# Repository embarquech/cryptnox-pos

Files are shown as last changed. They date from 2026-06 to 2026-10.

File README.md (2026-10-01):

<div align="center">



### cryptnox-pos

Standalone USDC payment terminal powered by a Cryptnox smart card and the Cheap Yellow Display

</div>

<br/>
<br/>






`cryptnox-pos` is a self-contained payment terminal firmware that runs on the
ESP32-2432S028 "Cheap Yellow Display" (CYD). It also serves as a reference
**dev kit** showing how to integrate the [`cryptnox-sdk-esp32`](https://github.com/embarquech/cryptnox-sdk-esp32)
into a real-world end-user product.

The user selects an amount on the touchscreen, taps a **Cryptnox smart card** on
the attached PN532 reader, and the terminal signs and broadcasts an EIP-1559
transfer via a JSON-RPC endpoint (PublicNode by default), then waits for the
on-chain receipt before showing **Approved**. The asset is picked on the device —
ETH, USDC or USDT on Ethereum, POL, USDC or USDT on Polygon, and TRX or USDT on
Tron. Whether those are the production networks or their test deployments
(Sepolia, Amoy, Nile) is a runtime setting on the config page; it defaults to
**production**, and the terminal restarts to apply a change. USDC on Tron is a
testnet-only selection — Circle wound it down in 2024&ndash;25.

> [!NOTE]
> The keypad enters two decimal places of whatever asset is selected, and a
> native-coin amount is signed as a `uint64` of wei — so **ETH and POL sales are
> capped at 18.44**. The keypad stops there rather than letting an operator key a
> figure the transaction cannot carry. The stablecoins are 6-decimal and keep the
> full 99999.99 range.

> [!WARNING]
> **Reference / educational dev kit — not a tamper-resistant terminal.**
> The ESP32 is not a secure microcontroller and has no protected RAM. The
> optional [secure build](#secure-build)
> (Flash Encryption + encrypted NVS + Secure Boot v2) protects secrets at rest
> and locks the boot chain, but at run time the card PIN (entered on-screen, not
> stored in the firmware) and the Wi-Fi password live in plaintext RAM —
> readable by anyone who can reach live memory (JTAG, a run-time exploit).
> **The Cryptnox Hardware Wallet remains the trust anchor** — private keys never
> leave the card, so a compromised ESP32 still cannot sign without it.

### Built on

- **[`cryptnox-sdk-esp32`](https://github.com/embarquech/cryptnox-sdk-esp32)** (git submodule) — secure channel, ECDH/ECDSA, PN532 transport, ESP32 crypto provider
- **[LVGL 8](https://lvgl.io/)** (managed component) — the touchscreen UI
- **[TFT_eSPI](https://github.com/Bodmer/TFT_eSPI)** + **[XPT2046_Touchscreen](https://github.com/PaulStoffregen/XPT2046_Touchscreen)** (git submodules) — CYD panel driver + touch, behind LVGL
- **[arduino-esp32](https://github.com/espressif/arduino-esp32)** as an ESP-IDF managed component (Arduino runtime for the display libraries; the rest stays on native IDF)

---

## Supported hardware

### Cryptnox Hardware Wallet smart cards

Works with Cryptnox Hardware Wallet smart cards running firmware v1.6.0 or later.

| Smart card | Wallet version |
|---|---|
| [Crypto Hardware Wallet – Dual Card Set](https://shop.cryptnox.com/product/hardware-wallet-smartcard-dual/) | v1.6.1 |

### NFC readers

| Reader | Type | Interface |
|---|---|---|
| [PN532 NFC Module](https://www.nxp.com/products/PN532) | Contactless (NFC/ISO 14443) | I²C |

### Host board

| Board | MCU | Display | Touch |
|---|-----|---|---|
| [ESP32-2432S028 "Cheap Yellow Display"](https://github.com/witnessmenow/ESP32-Cheap-Yellow-Display) | ESP32-WROOM-32 | ILI9341 240×320 (portrait) | XPT2046 (resistive) |

---

## Installation

1. Install **[ESP-IDF v5.5](https://docs.espressif.com/projects/esp-idf/en/v5.5/esp32/get-started/index.html)**
   (the project pulls `espressif/arduino-esp32` and `lvgl/lvgl` as IDF managed
   components; TFT_eSPI / XPT2046 are in-tree submodules).
2. Clone this repository **with submodules**:
   ```
   git clone --recursive https://github.com/embarquech/cryptnox-pos.git
   cd cryptnox-pos
   ```
3. Copy the credentials template and fill it in:
   ```
   cp config.template.h main/config.h
   ```
   `main/config.h` is gitignored — see [Configuration](#configuration) below.
4. Set the target, then build and flash from an ESP-IDF environment:
   ```
   idf.py set-target esp32
   idf.py -p PORT build flash monitor
   ```
   The first build also fetches `espressif/arduino-esp32` and `lvgl/lvgl` from
   the IDF component registry, so expect a longer initial compile.

> [!TIP]
> Open the IDF env first: on Windows run the "ESP-IDF PowerShell"/`export.bat`,
> on macOS/Linux `. $IDF_PATH/export.sh`. For the **secure (encrypted/signed)
> build**, see [Secure build](#secure-build)
> below — don't use plain `idf.py flash` on an already-provisioned board.

## Hardware setup

> [!CAUTION]
> Always double-check the wiring before powering the board to prevent damage.

The CYD exposes its free GPIOs on the **CN1** header. The firmware uses
the **I²C** interface to the PN532.

### CYD CN1 ↔ PN532 NFC — I²C interface

| PN532 Pin | CYD Pin / Label  | Wire Color |
|---|---|---|
| GND | GND | Black |
| VCC | 3.3V | Red |
| SDA | GPIO 27 (CN1 SDA)| Yellow |
| SCL | GPIO 22 (CN1 SCL)| Blue |

> [!IMPORTANT]
> Set the PN532 module's mode switches to **I²C = `1 0`**, as printed on the
> board: the switch marked **1** ON (HIGH), the switch marked **2** OFF (LOW).
> `0 1` is SPI.
>
> The PN532 reads the switches only at its own power-up, and its reset pin is not
> wired, so an ESP32 reset does not apply a change — unplug and replug the USB.

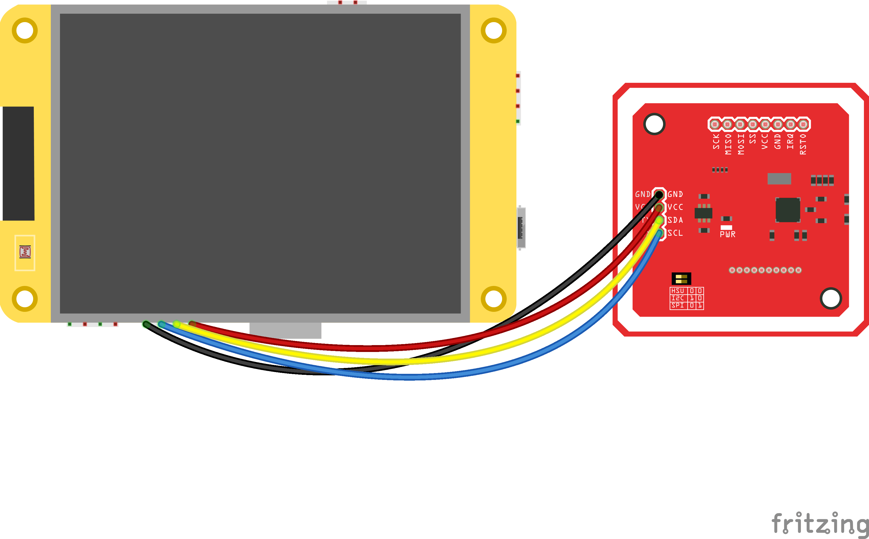
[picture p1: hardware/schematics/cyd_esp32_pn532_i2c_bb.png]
cyd_pn532_i2c


The display, touchscreen and backlight pins are already wired internally on the
CYD; the firmware drives them through TFT_eSPI's `ILI9341_2_DRIVER` in **portrait
rotation (240×320)**, with `invertDisplay(true)` + a GAMMASET fix for the panel
and a calibrated XPT2046 touch mapping. The backlight is PWM-dimmable (LEDC).

---

## Configuration

`main/config.h` is gitignored. Copy `config.template.h` to `main/config.h`
and fill in:

| Field | Description |
|---|---|
| `RPC_URL` | Ethereum JSON-RPC endpoint (PublicNode Sepolia by default; an Infura variant is provided commented-out) |
| `RPC_PROJECT_ID` / `RPC_API_SECRET` | Optional — only when using Infura (HTTP Basic Auth); leave undefined for PublicNode |
| `RPC_CA_CERT_PEM` | Optional — pin the RPC endpoint's TLS certificate; trusts only that cert instead of the full CA bundle. Undefined = Mozilla bundle |
| `ADDR_FROM` | Any valid Ethereum address, used only as the boot-time RPC reachability probe. The paying account is derived from whichever card is tapped (`m/44'/60'/0'/0/0`), not read from here |
| `ADDR_TO` | **Fallback** destination address, used until an operator sets one on the device. **Use the EIP-55 mixed-case checksum form** — the firmware verifies the checksum at boot and refuses to start on a mismatch. All-lowercase is accepted but bypasses that typo protection (and warns at boot) |
| `ADDR_USDC` | **Fallback** USDC ERC-20 contract address on the target chain (Sepolia testnet by default). Same EIP-55 rule as `ADDR_TO` |
| `ADDR_USDT` | USDT ERC-20 contract on Sepolia. Not settable on the device — the one NVS contract slot is USDC's — and not fatal if unset: USDT on Ethereum is then refused at the confirm step. Its `decimals()` **must be 6**. Same EIP-55 rule as `ADDR_TO` |
| `POLY_RPC_URL`, `CHAIN_ID_AMOY`, `POLY_ADDR_USDC`, `POLY_ADDR_USDT` | Polygon Amoy endpoint, chain id and the two token contracts on that network. Polygon reuses the whole Ethereum path — same card key, same payout address — so only these differ. `POLY_CA_CERT_PEM` pins its certificate; `POLY_MIN_PRIORITY_FEE_GWEI` (default 30) is the tip floor, since Amoy drops anything under ~25 Gwei and the fee steppers are shared with Ethereum |
| `TRON_ADDR_USDC` | USDC TRC-20 contract on Nile. Config-only and non-fatal, like `ADDR_USDT`. Testnet only: Circle wound USDC on Tron down in 2024–25, so there is no mainnet asset to graduate to |
| `RPC_URL_MAIN`, `POLY_RPC_URL_MAIN`, `TRON_URL_MAIN`, `CHAIN_ID_MAINNET`, `CHAIN_ID_POLYGON`, `ADDR_USDC_MAIN`, `ADDR_USDT_MAIN`, `POLY_ADDR_USDC_MAIN`, `POLY_ADDR_USDT_MAIN`, `TRON_ADDR_USDT_MAIN`, `TRON_ADDR_USDC_MAIN` | The production half of every pair above, selected at run time from the config page's Network section (default: production). Same rules throughout — EIP-55 form, `decimals()` **must be 6**, unset means that asset is refused rather than the terminal failing to boot. `tests/units/test_networks.cpp` checks each one parses; **verify against a block explorer** that it is the right contract before taking real money. A TLS pin applies to the production endpoint too, so it has to cover whichever network the terminal is switched to |
| `CHAIN_ID_SEPOLIA`, `MAX_PRIORITY_FEE`, `MAX_FEE`, `GAS_LIMIT_ERC20` | Chain ID and EIP-1559 gas parameters (the fees are first-boot defaults, editable at run time in the settings) |
| `GAS_LIMIT_NATIVE` | Gas for a plain ETH/POL transfer — exactly 21000, since no contract runs. Optional; defaults to 21000 |

**Not in `config.h`** — set on the device, never baked into the firmware:
- **Wi-Fi** — chosen during setup from a list the terminal scans, in a browser (stored in NVS).
- **Payout addresses and token contracts** — set during setup, either typed in a
  browser or read off the operator's own Cryptnox card, and accepted on the panel.
  The `config.h` values above are only the fallback; an asset with no address of its
  own is **not offered** on the amount screen.
- **Card PIN** — entered on the touchscreen keypad at sign time, scrubbed from RAM right after.
- **Transfer amount** — chosen on the keypad per transaction.

Setup itself is a browser flow — see [docs/config-portal.md](docs/config-portal.md):

```
 admin code    panel     the one secret that never touches a network
 QR code       panel     camera joins the terminal's AP; the page opens itself
 authorise     both      the browser asks, the panel takes the code
 addresses     browser   typed, or read off a Cryptnox card
 Wi-Fi         browser   picked from the terminal's own scan
 Finish        panel     restarts, which applies everything
```

---

## Secure build

By default the firmware and NVS are **unencrypted and unsigned** — fine for the
dev kit. An optional **secure build** hardens the device on three fronts:

| Feature | Effect |
|---|---|
| Flash Encryption | a flash dump is ciphertext, useless without the key |
| Encrypted NVS (`nvs_keys` partition) | the Wi-Fi password / fees in NVS are encrypted |
| Secure Boot v2 (RSA-3072) | only firmware signed with your key boots |

> [!CAUTION]
> These burn **eFuses — IRREVERSIBLE**. Validate on a **sacrificial board
> first**; a misconfigured burn bricks the unit. On the classic **ESP32**
> Secure Boot v2 supports **a single key with no revocation/rotation** (that
> is an S2/S3/C-series feature): if your signing key leaks you cannot revoke
> it, and if you lose it the board can never be updated again. Keep both keys
> **offline, in multiple copies**.

In the repo:
- `sdkconfig.defaults.flash_encryption` — **DEVELOPMENT** secure overlay: Flash
  Encryption (Development mode), `CONFIG_NVS_ENCRYPTION`, Secure Boot v2 +
  signing key, `ESP32_REV_MIN_3` (required for SBv2) and
  `PARTITION_TABLE_OFFSET=0x10000`. Stays reflashable, keeps verbose logs.
- `sdkconfig.defaults.release` — **RELEASE** overlay (layer on top): Flash
  Encryption *Release* mode + boot log off. Locks the board — no plaintext
  flash, no flash dump. Production only, irreversible.
- `partitions.csv` — the `nvs_keys` partition (inert in a normal build).
- `tools/secure_provision.py` — one-shot factory provisioning of a fresh board.
- `tools/secure_flash.py` — pre-encrypt + flash for routine reflashing.

**Step 1 — generate both keys, ONCE per product (store OFFLINE, gitignored):**
```
espsecure.py generate_flash_encryption_key --keylen 256 secure_keys/flash_encryption_key.bin
espsecure.py generate_signing_key --version 2 secure_keys/secure_boot_signing_key.pem
```

**Step 2 — build with the secure overlay** (the bootloader + app are signed
automatically at build time):
```
idf.py -D "SDKCONFIG_DEFAULTS=sdkconfig.defaults;sdkconfig.defaults.flash_encryption" build
```
(PowerShell: quote the whole `-D` argument as shown, because of the `;`.)

**Step 3 — provision a fresh board (one command, IRREVERSIBLE):**
```
python tools/secure_provision.py --port COMx --baud 921600 --yes
```
It checks the board is fresh, burns the flash-encryption key, enables Flash
Encryption, then flashes the signed + pre-encrypted bootloader/table/app. After
it finishes, **reset the board**: the bootloader finalizes Secure Boot on first
boot (burns the public-key digest + `ABS_DONE_1`). Verify:
```
espefuse.py --port COMx summary | findstr "FLASH_CRYPT_CNT ABS_DONE_1"
```
→ `FLASH_CRYPT_CNT` odd and `ABS_DONE_1 = True` = fully hardened.

**Routine reflash afterwards** (board already provisioned, Flash Encryption
active — never use plain `idf.py flash`, it would write plaintext the chip
mis-decrypts):
```
python tools/secure_flash.py --port COMx --baud 921600              # full
python tools/secure_flash.py --port COMx --baud 921600 --app-only   # app only
```
Because images are pre-encrypted on the host, `FLASH_CRYPT_CNT` is never
consumed. To **distribute** an encrypted image instead of flashing locally:
```
python tools/secure_flash.py --package    # -> dist/cryptnox_pos-encrypted-full.bin
```

> [!WARNING]
> Steps 2–3 use the `flash_encryption` overlay = **Development** mode: the board
> stays reflashable with verbose logs while you validate. For the locked
> **production** image, layer the release overlay on top and reflash:
> ```
> idf.py -D "SDKCONFIG_DEFAULTS=sdkconfig.defaults;sdkconfig.defaults.flash_encryption;sdkconfig.defaults.release" build
> ```
> Release mode permanently disables plaintext UART flashing + flash dumps and
> silences the boot log — IRREVERSIBLE, manufacturing only. Note: on the classic
> ESP32 encrypted NVS **requires** Flash Encryption (no HMAC eFuse scheme), so
> the two cannot be separated.

---

## Payment flow

1. **Splash** — Cryptnox logo + spinner while Wi-Fi / SNTP / RPC / wallet come
   up (version shown at the bottom).
2. **Amount** — numeric keypad (cents entry); tap **Charge**.
3. **Send** — Ledger-style review showing the amount, the destination address
   and the USDC contract **in full**; tap **Confirm** or **Cancel**.
4. **PIN** — enter the card PIN on the on-screen keypad (validated, then wiped
   from RAM after signing — never stored).
5. **Transaction** — tap the Cryptnox card on the PN532:
   **Processing** (opening the secure channel) → **Signing** (the card signs
   `keccak256(unsigned_tx)`) → **Authorizing** (work out the `v` parity locally
   against the card's own public key, RLP-encode the EIP-1559 tx, broadcast via
   `eth_sendRawTransaction`) → **Confirming** (poll `eth_getTransactionReceipt`
   until the tx is mined).
6. **Approved / Declined** — Approved **only** on a mined receipt with
   `status 0x1`; tap **New sale** to start the next transfer.

> [!NOTE]
> The card must have a seed loaded and the BIP-32 derivation path
> `m/44'/60'/0'/0/0` available. Provision it once with the
> [Cryptnox CLI](https://github.com/cryptnox/cryptnox-cli):
> ```
> cryptnox initialize
> cryptnox seed generate
> ```

---

## Troubleshooting

- **Inverted colours / banding on gradients** → the CYD panel needs `invertDisplay(true)` (inverted colours) and a GAMMASET tweak (banding/"milky gamma"); both are already applied in `ui_task`. If the screen is blank/scrambled your board may use the other ILI9341 variant — set `CONFIG_TFT_ILI9341_DRIVER=y` (instead of `_2`) in `sdkconfig.defaults` and rebuild.
- **Touch hitboxes are offset** → calibrate the panel: burger menu → admin code → **Screen** → **Touch**. Two crosses to tap, then Keep or Discard the result, and an un-confirmed calibration puts the old one back after 20 s — so a bad one cannot lock you out of the screen that fixes it. The defaults (raw 200..3800) match the panel shipped with the 2432S028. The stored range lives in NVS, so it goes the way every other setting does: a factory reset or a firmware update with a new `BUILD_ID` clears it and the panel is back on the defaults.
- **`Card not found`** → confirm the PN532 switches are set for I²C (`1 0`, then power-cycle), the SDA/SCL wires match GPIO 27/22, and the card is well centred on the antenna. `pn532: No ACK from PN532` at boot means the reader is not answering at all — almost always the switches. A reader that stops answering later is re-initialised by the driver on its own (`re-initialising the reader` in the log).
- **`Signature check failed`** → the card's signature did not verify under the public key it exported for the same path. That is an internal inconsistency (card or derivation), not a setup error — retry with the card held still; if it repeats, the card needs looking at.
- **WiFi connect fails** → only WPA2 is supported; check SSID/password.
- **App partition full** → the project uses two 1.94 MB OTA app slots (`partitions.csv`) on a 4 MB flash, so the budget is half what a single-slot table would give — a "% free" that halved between two builds is almost always that table, not growth. Where the space actually goes, biggest first: the image assets in `.rodata` (`chain_icons.c`, `logo_img.c` — ~40 KB between them), then LVGL and the fonts it pulls in. Regenerate an asset smaller (`tools/gen_*.py`), or trim the panel fonts: they are generated by `tools/gen_fonts.py` into `main/fonts/*.c` (Plus Jakarta Sans + Inter, 4 bpp — the LVGL built-in Montserrat fonts are already off), so fewer sizes or a narrower glyph range there is where font space comes back; check with `idf.py size-components` before assuming a subsystem is to blame.
- **`Update` says the terminal has no second firmware slot** → that unit was flashed with the old single-app partition table. The table itself is never rewritten by an update, so it needs one reflash over USB first. See [docs/ota.md](docs/ota.md).

---

## Documentation

The generated documentation for this project is available [here](https://embarquech.github.io/cryptnox-pos/).

- [The config portal](docs/config-portal.md) — setup and administration on the terminal's own SoftAP: why that AP is the radio's only interface while the page is up, why the admin code is only ever typed on the panel, and the endpoint list. Test plan: [docs/testing-provisioning.md](docs/testing-provisioning.md).
- [Firmware updates over Wi-Fi](docs/ota.md) — the browser-mediated OTA path, publishing a release, and the signing key you must not ship without. Test plan: [docs/ota-testing.md](docs/ota-testing.md).

---

## License

`cryptnox-pos` is dual-licensed:

- **LGPL-3.0** for open-source projects and proprietary projects that comply with LGPL requirements
- **Commercial license** for projects that require a proprietary license without LGPL obligations

For commercial inquiries, contact: contact@cryptnox.com

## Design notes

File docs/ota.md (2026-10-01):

# Firmware updates over Wi-Fi

The terminal never connects to GitHub. A browser does, and carries the bytes:

```
 you:     download cryptnox_pos.bin anywhere with internet
 browser ──HTTP──>  http://192.168.4.1/api/ota                  streamed to flash
 panel:   operator accepts the version → reboot into the other slot
```

Why the browser and not `esp_https_ota`, which would be a tenth of the code: a
terminal that phones a third party for updates tells that third party how many
units exist, roughly where they are and what each one runs. Nobody needs a
register of deployed payment terminals, least of all one kept by somebody else.

Firmware slots and image verification are `main/ota.cpp`, and the reasoning lives
in `main/ota.h`. The page, the endpoint and the authorisation belong to the config
portal — see **[config-portal.md](config-portal.md)**, which is also where the
addresses and contracts are set. Firmware is one section of one page.

## Why the flow has this shape

The page is on the terminal's own SoftAP and nowhere else — that AP is the
radio's only interface while the config portal is up, which is what keeps the
payout forms off the venue LAN (see
[config-portal.md](config-portal.md)). So the browser reading the page is on a
network with no route to the internet, and there is exactly one way to feed it an
image: **Browse**, and pick a `.bin` that is already on the phone or laptop.
Download it — desk, phone, USB stick — *before* joining the terminal's AP.

There used to be a "Check for updates" button that fetched a `firmware.json`
release list from the browser. It is gone. It only ever worked when a phone
happened to keep cellular data alive alongside a Wi-Fi network with no route,
which is not something to build on, and the other 90% of the time it was a
button whose only output was a network error. Publishing a release is now
publishing a signed `.bin` somewhere people can download it.

### What the transport is worth, and what it is not

The **firmware** does not need the transport to be trustworthy — it is verified
against a signing key compiled into the running image (see below), so a modified
upload is rejected whatever the network did to it.

The **admin code** is not on the network at all. It is typed on the terminal's own
screen to authorise the browser, and the browser then carries a random session
token; there is no code field in the page and no `X-Admin-Code` header any more.
See the authorisation section of [config-portal.md](config-portal.md).

The page is served over plain HTTP on the terminal's own WPA2 SoftAP, which
admits one station at a time and is the radio's only interface while the portal is
up. That link, not a certificate, is what protects the session token and the
addresses on the page — and neither is what keeps a stranger's firmware off the
device. The signature is.

## Operating it

1. Settings → About → **Update** (or Wi-Fi → **Configure**; same page). The panel
   shows a QR code for the terminal's own Wi-Fi, the SSID and passphrase in text,
   and starts a **15-minute** window (`PROV_WINDOW_MIN`). Tapping **Done** closes
   it immediately — and puts the terminal back on its network, which it leaves for
   the duration.
2. Scan the code with a phone camera to join, and the page opens itself. The panel
   asks for the admin code; enter it there. Then **Browse** and pick the `.bin`
   (see above — download it *before* joining). Picking it starts the transfer;
   there is no second confirm button, because nothing the page does installs
   anything.
3. The terminal verifies the image and asks on its own screen. Nothing reboots
   until somebody accepts it there — the same rule payout addresses follow: a
   browser may propose, only the panel may accept. A version that goes
   *backwards* is called out in red.
4. First boot after an update is on probation. `ota_mark_valid()` runs only once
   the panel, the card reader and the wallet layer have all come up; a reset
   before that point returns the bootloader to the previous slot. The network is
   deliberately not part of it: the first boot after an update runs setup (the
   update wipes the settings), and a power cut or an RPC outage during setup must
   not roll back an image that works.

## Publishing a release

There is no manifest and no URL compiled into the firmware: a release is a
signed `cryptnox_pos.bin` put somewhere operators can download it (a GitHub
release asset is fine), fetched *before* joining the terminal's AP and then
picked with **Browse**.

The version is built from git, never from a file: `<latest tag>-<first-parent
commit count>-g<short hash>`, e.g. `v1.0.0-91-gc10d526` (project
`CMakeLists.txt`). A release is a tag — `git tag v1.1.0` on the release commit,
then push the tag. The commit count doubles as `BUILD_ID`, which decides whether
the terminal wipes its settings on first boot. The panel
compares the uploaded image's version with the running one and calls out a
*downgrade* in red before anything is installed. Ordering is dotted-numeric with
an optional leading `v`; anything after the numbers (`-rc1`, `+sha`) is ignored
rather than ordered (`main/ota_version.h`, `tests/units/test_ota_version.cpp`).

## Signing — do not ship without this

The terminal cannot validate a TLS certificate chain to GitHub, because it never
talks to GitHub. Its only way to know an image is genuine is a signature over
that image, checked against a public key compiled into the firmware already
running. The secure build turns that on — `sdkconfig.defaults.flash_encryption`
enables hardware Secure Boot v2, and `sdkconfig.defaults.release` stacks on top
of it — and `esp_ota_end()` refuses anything that fails it, before the staged
slot can ever become bootable.

Without it, `POST /api/ota` is one authorised browser session away from replacing
the firmware on a device that signs cryptocurrency transactions. The session token,
the 15-minute window and the on-screen accept are not a substitute — they make it
harder to reach, not impossible, and none of them can tell a genuine image from a
convincing one.

This is **hardware** Secure Boot v2: the first boot of a secure build burns the
signing key's digest into eFuse, and that is one-way — from then on the unit only
boots, and only installs, images signed with the same key. (An earlier version of
the release overlay tried to add the software-only variant on top; Kconfig drops
it whenever `CONFIG_SECURE_BOOT` is set, so both overlays now name the one model
and the one key.)

Generate the key once:

```sh
idf.py secure-generate-signing-key --version 2 secure_keys/secure_boot_signing_key.pem
```

Keep it out of this repository and off any build machine you do not control; it
is the whole of the trust anchor. Losing it means no unit already in the field
can ever be updated again. The RSA scheme needs ESP32 revision v3.0 (ECO3) —
if `esptool.py chip_id` reports less, switch to
`CONFIG_SECURE_SIGNED_APPS_ECDSA_SCHEME` and drop `CONFIG_ESP32_REV_MIN_3`.

## Flash budget

`partitions.csv` carries two 1.94 MB app slots (`ota_0`, `ota_1`) — the largest
64 KB-aligned pair that fits in 4 MB alongside the data partitions. The image is
~1.6 MB, so there is roughly 390 KB of headroom; check `idf.py size` before
adding fonts or images.

**A unit flashed with the old single-slot table cannot be updated over the air.**
The partition table is never rewritten by an update, so those units need one
serial reflash before any of this applies to them.

## Endpoints

Firmware uses two of the portal's; the full list is in
[config-portal.md](config-portal.md).

| | |
|---|---|
| `GET /api/state` | includes `version`, the running firmware's, for the page's header |
| `POST /api/ota` | image body, `X-Prov-Token` header, streamed to the idle slot |

Same-origin, so no CORS headers are needed on the device side and no preflight
happens. The page does not hash the file itself — `crypto.subtle` is not even
available to it, since `http://192.168.4.1/` is not a secure context, and there
would be no point if it were: the image carries its own SHA-256 and
`esp_ota_end()` is what checks it, along with the signature, on the device that
has to trust the result.

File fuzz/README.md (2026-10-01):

# Fuzzing — cryptnox-pos parsers

libFuzzer + AddressSanitizer harnesses for the three byte-parsing surfaces in
this firmware. Same pattern as the SDK's `cryptnox-sdk-cpp/fuzz` (single-TU
harness, ASan, corpus dir).

| Harness | Target | Source under test |
|---|---|---|
| `fuzz_eth_rlp` | `eth_rlp_encode_unsigned` / `_signed` | `main/eth_rlp.cpp` |
| `fuzz_parse_address` | `eth_addr_parse` | `main/eth_addr.cpp` |
| `fuzz_eth_rpc_json` | `eth_json_result_string` + `eth_json_receipt_status` | `main/eth_json.cpp` (+ cJSON, `CW_Utils`) |

Each harness `#include`s the production `.cpp` under test directly — **no
copies**, so the fuzzers can never drift from the firmware. The two parsers
that used to be `static` inside ESP-IDF-welded translation units now live in
their own pure units (`eth_addr.cpp`, `eth_json.cpp`) precisely so both the
firmware and the fuzzers share one source.

The `eth_json` parsers are the only ones fed straight from the network (HTTP
response bodies), so `fuzz_eth_rpc_json` is the highest-value target — it runs
both JSON entry points (`result` extraction and receipt classification) over
each input.

## Build

Linux / macOS, or WSL on Windows. Requires `clang` (libFuzzer) and, for the
JSON target only, `IDF_PATH` exported so cJSON can be found.

```sh
cd fuzz
mkdir build && cd build
cmake .. -DCMAKE_C_COMPILER=clang -DCMAKE_CXX_COMPILER=clang++
make                       # builds all available targets
```

If `IDF_PATH` is unset the JSON target is skipped (a warning prints) and the
other two still build. To point at cJSON manually:
`cmake .. -DCJSON_DIR=/path/to/cJSON`.

## Run

```sh
./fuzz_eth_rlp        ../corpus/eth_rlp        -max_len=4096 -jobs=4
./fuzz_parse_address  ../corpus/parse_address  -max_len=64   -jobs=4
./fuzz_eth_rpc_json   ../corpus/eth_rpc_json   -max_len=4096 -jobs=4
```

A crash drops a `crash-<hash>` reproducer in the working directory; replay with
`./fuzz_<target> crash-<hash>`.

## Corpus

Seed files live under `corpus/<target>/`. They are starting points — libFuzzer
mutates and grows them.

- `eth_rpc_json/*_mainnet.json` are live Ethereum mainnet responses captured
  2026-09-30 from a public node: a USDC `Transfer` receipt, a balance, a fee
  history, the USDC `decimals()` call, an unknown-hash `null`, and a node
  refusing a malformed raw transaction. `error_nonce_too_low_geth.json` is
  geth's wording, hand-written.
- `eth_rlp/*.bin` follow the harness layout (six big-endian u64 scalars, the
  20-byte `to`, one parity byte, calldata): USDC `transfer` on mainnet and
  Polygon as the terminal builds them, a native ETH transfer, and all-ones
  scalars.
- `parse_address/` covers EIP-55 mixed case, a single flipped-case checksum
  failure, all-lowercase, one nibble short, and surrounding whitespace.

## Replaying the corpus without clang

`replay_main.cpp` stands in for libFuzzer's `main` and feeds each file to the
harness once, so the corpora double as a regression test with plain g++
(Windows included). `scripts/checks.sh` runs all three this way:

```sh
g++ -std=c++14 -Icryptnox-sdk-esp32/cryptnox-sdk-cpp     fuzz/fuzz_eth_rlp.cpp fuzz/replay_main.cpp -o r && ./r fuzz/corpus/eth_rlp/*
```

CI (`.github/workflows/tests.yml`) runs each harness for 60 s under clang +
ASan and keeps any `crash-*` input as a build artifact.

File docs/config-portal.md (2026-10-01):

# The config portal

One web app configures a terminal, in two modes. Implementation is
`main/provision.cpp`; the reasoning lives in `main/provision.h`.

| | **Wizard** (`PROV_MODE_WIZARD`) | **Admin** (`PROV_MODE_ADMIN`) |
|---|---|---|
| When | blank terminal, or saved Wi-Fi unreachable | any time, from the settings menu |
| Network | the terminal's own WPA2 SoftAP | the same SoftAP |
| Reached by | captive portal — the browser opens itself | the same captive portal |
| Transport | plain HTTP, port 80 | plain HTTP, port 80 |
| Closes | when setup ends | after `PROV_WINDOW_MIN` (15 min), or **Done** |
| Serves | one step at a time | everything at once |

The modes differ in what they serve and when they close. They do not differ in
how they are reached — that is the point of the next section.

## Authorisation: the panel, never the wire

There is no admin-code field in the page. The browser asks to be let in; the
terminal shows its admin-code screen; the operator types the code **on the panel**;
the session becomes authorised and carries a random 128-bit token
(`X-Prov-Token`) from then on.

So the code never crosses the network in either direction, on either mode's
transport, and a browser that can reach the page without the terminal in reach can
do nothing at all. (One exception, in the wizard only: the Wi-Fi-only re-join below
asks for no code at all.) Guessing at the panel earns the same escalating lockout the
settings menu imposes — it is the same screen and the same counter, so this is not
a cheaper door.

Everything that decides where money goes goes further than that. A browser may
**propose** a payout address or a token contract; the value is then displayed on
the panel and somebody has to accept it there. Nothing is stored until they do,
and the same is true of firmware: an upload is verified and staged, and only an
on-screen accept makes it bootable.

## The SoftAP is the only interface, and that is the security model

`esp_http_server` binds every interface and gives you no bind address. So a portal
running beside a station association is not "on the AP" — it is on the venue LAN
too, answering the payout forms to every device holding the venue PSK. The
perimeter this module relies on is *a passphrase shown on the panel to whoever is
standing there*, and on a venue LAN that perimeter is not merely weaker, it is
absent.

So `net_ap_start()` raises the AP in `WIFI_MODE_AP`, not APSTA, and drops the
station association on the way in. Both modes. The station comes back in
`net_ap_stop()` — the driver still holds the credentials, so it is a reconnect,
not a reconfigure, and closing the admin page puts a working terminal back online
rather than leaving it offline until somebody reboots it.

Two calls borrow the station back, for as long as they need it and no longer:
`net_wifi_scan()` flips to APSTA for the scan and hands the radio straight back,
and `net_wifi_connect()` holds APSTA for the join the operator asked for — the
phone that submitted the form is on the AP and has to be told what happened. The
caller then either keeps the join and stops the portal in the same breath, or
drops the association again (`net_wifi_disconnect()`, which also returns the radio
to AP-only).

**Consequences, stated plainly.** There is no remote administration: you are in
front of the terminal or you are nowhere. The terminal is off its network while
the admin page is open, so it is not taking payments during that window — which
is fine, because somebody is standing at it with the panel in one hand and a phone
in the other. And the browser-side update check needs the *phone's* internet, not
the terminal's, so on a phone with no cellular data the release-list check fails
and says so; the file picker still works.

**Both modes are plain HTTP**, and that is not laziness in the plaintext one:

* A captive-portal probe fetches a bare `http://` URL on port 80 and will not
  follow a redirect to 443. TLS means the phone's browser never opens by itself,
  which is the entire feature.
* The link is already encrypted — a WPA2 SoftAP whose random per-session
  passphrase is on the panel in front of the operator, admitting one station at a
  time, existing only while the portal does.
* The admin code is not on that link, and the values that are get confirmed on the
  panel.
* There is nothing else on the wire: the AP is the radio's only interface.

TLS on top of that would buy a certificate warning to explain on a 2.8" panel, a
self-signed key to generate and keep in NVS, a second transport through the same
forms, and no security anybody can point at. It used to be there; it is gone
(`CONFIG_ESP_HTTPS_SERVER_ENABLE` is deliberately off in `sdkconfig.defaults`),
and the leftover `tls_crt`/`tls_key` NVS entries on an already-provisioned unit
are erased the next time a portal opens (`ap_pass_load()`).

The AP passphrase is drawn once — on the first portal a unit ever opens — and kept
in NVS until `settings_factory_reset()` erases the `prov` namespace. It used to be
redrawn per session, on the grounds that the screen showing it is a screen a
customer can photograph. That defended one thing: the Wi-Fi-only re-join portal
asks for no admin code, so an old photograph can be used to join the setup AP and
change which network the terminal joins — but only while the terminal has that
portal open (it opens it by itself when the venue network fails), only from inside
the SoftAP's range, and only in front of a panel that is displaying the current
passphrase anyway. One association is all the AP allows, so a stranger using it
locks the operator out rather than watching them. Everything that moves money is
behind the admin code, which is typed on the panel and never on the page. What the
redraw cost was real: ten characters retyped every single time the page is opened.

Entropy comes from `esp_random()`, called after `net_wifi_init()` — the RNG is only
a true one with the RF subsystem running. `bootloader_random_enable()` (the SAR ADC
source, for entropy with the radio off) is deliberately *not* used: it must not be
called with Wi-Fi started, and by the time a portal opens it is.

## The wizard flow

```
 1. admin code       panel     the one secret that never touches a network
 2. QR code          panel     camera joins the SoftAP; portal opens the page
 3. authorise        both      browser asks, panel takes the code
 4. addresses        browser   typed, or read off a Cryptnox card
 5. Wi-Fi            browser   scanned list from the device's own radio
 6. Finish           panel     restarts, which is what applies everything
```

Steps 1 and 6 are on the panel, and the four in between are in the browser. There
is deliberately **no "use this screen instead"** escape: typing a payout address or
a venue passphrase on a resistive 240x320 panel is the thing this module exists to
avoid, and a second, worse path meant maintaining two of everything. The panel
picker still exists (`wifi_picker()` in `main/boot.cpp`) but it is now the
settings-menu route and the fallback for when the SoftAP itself will not come up.

**A configured terminal whose network has gone** gets `2 → 5 → 6`, and no admin code:
the addresses are already set and there is no code to create, so the page opens
straight on the Wi-Fi card and the first browser to ask is let in
(`prov_set_wifi_only()`). Three screens guarding a form whose only unconfirmed power
is "try this network" is three screens between an operator and a working till.

What still holds in that flow: the AP passphrase — per device, per session, on the
panel in front of whoever is asking — is the perimeter, and every value that decides where money
goes, or which firmware boots, is still accepted on the panel. The panel drops the
step numbers there, since there are no steps 1, 3 or 4 to count.

For that perimeter to mean anything the SoftAP has to be the *only* way in — which
is why the radio is AP-only while a portal is up (above). The Wi-Fi step is the one
place that has to open the station again, so a join that works is either kept and
the portal stopped in the same breath, or dropped again (`net_wifi_disconnect()`): a
network that associated but had no clock is rejected, and leaving that association
up would put the setup forms in front of everyone holding the venue PSK.

### The last screen the phone gets

Joining the venue network is where the page runs out of device to talk to: the
radio serves both networks for a few seconds and then follows the venue AP to its
channel, which drops the phone. So handing over the network does not leave the
operator on a Wi-Fi form with dead buttons — the page replaces itself with
**Configuration complete / follow the instructions on the terminal's screen**,
which is the truth: from here the panel is the only thing that knows anything.

That screen is not final, though. If the join fails the terminal comes back on the
same setup AP, the phone rejoins it by itself, and the poll that never stopped
running sees the device answer *with a note* — which is the only thing that brings
the page back to the Wi-Fi step, carrying the reason. An answer with nothing to
report is the join still being attempted, and must not undo the screen
(`tools/test_portal_render.js` asserts both).

A join that *works* is silence: the terminal stops the portal and the AP goes with
it, so nothing ever answers that poll again. Which is correct — there is nothing
left for the phone to do.

**Finishing restarts the terminal.** The recipient and contract dual stores are
built at boot from validated strings, so applying a change in place would mean a
second path into the money code that has to re-validate everything the boot path
already validates. Three seconds during setup buys reusing those checks verbatim.

### Payout addresses from a Cryptnox card

The alternative to typing 42 characters. One tap reads both networks —
`m/44'/60'/0'/0/0` for Ethereum, `m/44'/195'/0'/0/0` for Tron — and each address
goes through the same accept-on-the-panel handshake a typed one does, because "the
card said so" is not the same claim as "the operator checked it". A customer's card
presented at the wrong moment would otherwise redirect the takings.

The card will not export a public key without a verified PIN, so this needs the
card PIN on the keypad first, exactly as signing does.

**A card that was never set up is named as such.** A card out of its envelope has
no PIN and no key, and the applet says so in the clear in its SELECT response —
so that is read before the secure channel, on the payment path as well as this one
(`main/card_status.h`, `card_fault()` in `main/card_io.cpp`). Without it the holder of
a blank card is told *"Wrong card PIN"*, which is the one message that sends them
off to type it again. A response this cannot judge — a card type it has not been
told about, a SELECT that did not answer `90 00` — is not a refusal: the ordinary
paths report whatever happens next, and a parser that guessed here would turn a
working card away at a till.

The Ethereum address is rendered in EIP-55 mixed case (`eth_addr_format`). That is
not cosmetic: it is the form the operator's own wallet shows, which is what they are
being asked to compare against, and it means the stored string carries a checksum
so the boot-time parse is a real check on it.

## An asset with no payout address is not offered

A terminal set up for Ethereum and interrupted before Tron used to keep offering
Tron payments — to the `config.h` recipient, which is somebody else's address, while
looking entirely normal. Three things changed:

* the network picker greys out a network with no stored payout address, saying so
  rather than hiding the row;
* the Tx tab says in red when the recipient shown is the built-in default;
* boot corrects a stored chain selection whose payout address was never set,
  switching to one that was (`main/boot.cpp`, after the address resolution).

`settings_has_payout()` is the question being asked, and it means *stored*, not
*resolvable* — the `config.h` fallback still supplies the value, it just no longer
counts as configured.

There are two payout addresses for three networks. Polygon is EVM — same card key,
same `m/44'/60'/0'/0/0` derivation, same `0x` address — so it spends the Ethereum
one, and `settings_has_payout(false)` is what the Polygon row in the picker asks.
The page and the panel both say so where the address is entered and where it is
accepted; without that, an operator hunts for a Polygon field that will never exist
and concludes the terminal cannot take Polygon payments.

## Every setting is changed here, not on the panel

The panel is a 2.8" resistive screen behind an admin code; this page is a keyboard.
So the terminal's own settings screen **reports** and does not edit — brightness is
the single exception, because it is a property of the screen you are looking at and
nothing else can judge it. The Tx tab shows the asset, the token contract, the
payout address and the two gas caps as read-only rows; the gas caps were `+`/`-`
steppers there until they moved to this page.

Three panel controls are deliberately *not* settings, and stay where they are:

* the asset selector — on the amount row and at the top of the Tx tab. Which asset
  a sale is charged in is a shift-time choice made with a customer waiting, not
  something an administrator sets once;
* the factory reset on the About tab — the recovery path, which has to work when
  this page cannot be reached at all;
* the Wi-Fi picker the terminal raises by itself when it cannot re-join, for the
  same reason.

A gas cap is stored straight from this page rather than proposed on the panel like
an address: an address decides *who* gets the money and has to be read back by a
human, while a cap only decides how much gas the terminal pays for its own
transaction — and a wrong one announces itself by pricing the next sale out of a
block.

### Production or test networks

The Network section switches all three networks at once between their production
and their test deployments — Ethereum/Sepolia, Polygon/Amoy, Tron/Nile. Not one
per network: "Ethereum mainnet with Tron on Nile" is not a configuration anybody
wants, it is a terminal half of whose sales settle in nothing. A terminal that has
never been told otherwise is on **production**; a unit somebody bought to take
money with must not come up settling nothing.

Stored straight through like the gas caps and for the same reason — it cannot send
money anywhere, it only decides where the operator's own payout address is paid —
and then **the terminal restarts**. That restart is the mechanism, not an
inconvenience around one: the RPC endpoints, the chain ids and the token contracts
are resolved once at boot into the dual stores that every signature is reconciled
against, and there is no honest way to move those under a running payment.

Two things are stored per network and one is not:

* **token contracts** are per network. The same USDC on mainnet and on Sepolia are
  different deployments, so one slot would carry a testnet address onto mainnet —
  an address that holds nothing, under a name that says it holds money. Switching
  therefore falls back to the firmware's own contract for the network you arrive
  on until somebody sets one there;
* **payout addresses** are shared. A card's address is the same account on either
  deployment, so switching does not send the operator back through setup.

The names on the panel follow: the Tx tab and the asset picker read "Ethereum
Sepolia" on a test terminal and plain "Ethereum" on a production one. The mainnet
names carry no suffix on purpose — a production terminal should not be shouting a
word nobody needs, and the testnet ones then stand out.

The addresses themselves live in `config.h`, one pair per asset, and
`tests/units/test_networks.cpp` checks every one of them parses with a correct
EIP-55 checksum. What no test can check is that an address is the *right*
contract; that is a block explorer's job before a terminal takes real money.

## Endpoints

Everything except `GET /` and `GET /api/state` requires the session token.

| | |
|---|---|
| `GET /` | the page — HTML then JS, two strings in `provision.cpp` |
| `GET /api/state` | mode, step, `authed`, version; and once authorised the addresses, contracts, SSID, pending value, note, `mainnet`, gas caps, scan generation |
| `GET /api/scan` | the device's last Wi-Fi scan |
| `POST /api/auth` | ask to be authorised → returns the token; the panel decides (except the Wi-Fi-only wizard, which grants it) |
| `POST /api/payout` | `net=eth\|tron`, `addr=…` → proposed, panel confirms |
| `POST /api/contract` | same shape, for the ERC-20 / TRC-20 contract |
| `POST /api/fees` | `max=…`, `prio=…` in Gwei → stored directly, 1&ndash;500 each and the tip no higher than the max |
| `POST /api/network` | `net=main\|test` → stored directly, then the terminal restarts to apply it |
| `POST /api/card` | read the payout addresses off a Cryptnox card |
| `POST /api/wifi` | `ssid=…`, `pass=…` |
| `POST /api/rescan` | ask the device to scan again |
| `POST /api/next` | wizard: leave this step |
| `POST /api/ota` | firmware image body (see [ota.md](ota.md)) |

Bodies are `application/x-www-form-urlencoded` and parsed by `form_field()`
(`main/form_parse.h`), which is the one piece of this that reads input a stranger
controls and is therefore host-tested — `tests/units/test_prov_form.cpp`, and
`test_addr_check.cpp` for the address checks it feeds.

### Why the Wi-Fi scan is not in the handler

Scanning makes the radio hop channels, which briefly drops whoever is joined to the
SoftAP — including the browser making the request. So `net_wifi_scan()` runs on the
main task at known moments (entering the Wi-Fi step, or a rescan the browser asked
for) and hands the result to `prov_set_scan()`; the handler serves the cached list.
The page refetches when `scan_gen` moves.

In admin mode a scan interrupts the page rather than the AP, which is why the
rescan there is an explicit button and the page says what it will do.

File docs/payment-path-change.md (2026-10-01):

# Any card, and a funding check

Why the EVM payment path now takes its sender from the tapped card, why a
balance check could not be added without that, and what each of them changed.

Written against the code in this repo — every claim below names the file that
implements it, so a reader can disagree with the code rather than with this
document.

Scope: the sale path on Ethereum, Polygon and Tron. Not the card applet, not the
setup flow, not the UI.

---

## 1. What the code did before

On Ethereum and Polygon, `sign_and_broadcast()` built the whole transaction
**before the customer tapped**:

```
eth_rpc_select()         from-address = "0x" ADDR_FROM, straight from config.h
eth_rpc_get_nonce()      the nonce of THAT account
build the EIP-1559 tx    chain id, that nonce, fees, gas, recipient, amount
RLP encode + keccak256   the hash that will be signed
── card_connect() ──     only now does the customer tap
verifyPin()
card_sign()              the card signs that hash
ecrecover_parity()       recover the signer, compare against ADDR_FROM
eth_rpc_send_raw_tx()    broadcast
```

The nonce is per-account, so by the time anyone presented a card the
transaction was already committed to one specific account: the one whose
address was compiled into `main/config.h` as `ADDR_FROM`.

Tron never worked this way. `sign_and_broadcast_tron()` connects to the card
first, derives the sender from its public key
(`getPublicKey` → `CW_Tron::addressBytesFromPublicKey`), and only then asks the
node to serialise a transfer — because Tron will not build one without knowing
who is sending.

---

## 2. The two defects that came out of that ordering

### 2.1 Only one card could pay on EVM

A card that was not `ADDR_FROM`'s signed perfectly well — the card has no idea
what address the terminal believes it holds — and was then rejected at
`eth_rpc_ecrecover_parity()`, which recovers the signing address from the
signature and compares it against the configured one. Neither parity matched,
so the sale was declined **after the customer had entered their PIN and
tapped**.

Nothing was broadcast and nothing was spent, but nothing could ever succeed
either. The behaviour was known and documented — the README's troubleshooting
section carried it as an expected error:

> `ecrecover did not match either parity` → `ADDR_FROM` in `config.h` does not
> correspond to the card's `m/44'/60'/0'/0/0` derived key.

What had not been decided was whether it was intended.

### 2.2 Nothing checked whether the payer could fund the sale

There was no balance query anywhere in the firmware, on either chain. An
underfunded card was discovered by the network, at the end of the flow:

| Shortfall | What happened before | Cost to the customer |
|---|---|---|
| Gas, on EVM | The node refused the broadcast; `rpc_error.h` turned its message into a panel line ("Fee too low", "insufficient funds for gas * price + value") | PIN, tap and signature spent on a sale that could not settle |
| Tokens, on EVM | Nothing refused it. The transaction is valid, so it broadcast, mined and reverted | The whole confirmation wait, **and the gas for the failure** |
| TRX, on Tron | `tron_rpc_create_transfer()` will not build a transfer from an account the chain cannot fund, so this failed before signing — by accident, not by design | Reported as `No TRX on <address>` |
| Tokens, on Tron | Nothing refused it. Creating a `TriggerSmartContract` is only serialisation; the node builds it whether or not the account holds the tokens | Signed, broadcast, failed on-chain |

The token cases are the worse half: a refusal is cheap, a mined revert is not.

---

## 3. Why the two could not be fixed separately

A funding check has to know whose funds to check.

On EVM that answer only existed early *because* the payer was hardcoded. A
check placed before the tap would have been asking about the integrator's own
account — not the customer's — and would have cemented the one-card limit
rather than exposing it. Moving the check later without changing the sender
would have been strictly worse than leaving it alone: a later refusal, and
still only one card able to pay.

Tron is what made the choice unavoidable. Any card already worked there and one
card worked on EVM, so the same terminal behaved differently depending on which
asset the operator had selected. Reconciling them is a product decision — a
demo bound to one card, or a terminal that accepts customers — not a code one.

---

## 4. What changed

### 4.1 The EVM sender comes from the card

`sign_and_broadcast()` now connects to the card and verifies the PIN before
anything that depends on the account, then derives the sender the same way the
setup flow already derives a payout address from a card: `keccak256` of the
uncompressed public key at `m/44'/60'/0'/0/0`, low 20 bytes, formatted by
`eth_addr_format()`.

That address is installed with `eth_rpc_set_from()` (`main/eth_rpc.cpp`), which
**copies** the string — unlike `eth_rpc_init()`, whose pointer contract suits a
`config.h` literal and not an address derived into a stack buffer during one
sale. A malformed address is refused rather than ignored, because leaving the
previous payer in force would fetch somebody else's nonce.

`ADDR_FROM` survives only as the address for the boot-time RPC reachability
probe. It is no longer a whitelist of one.

One consequence worth recording: `ETH_RPC_PARITY_MISMATCH` used to mean "wrong
card", because it compared against `config.h`. Both sides now come from the card
that just signed, so a mismatch is an internal inconsistency — the message is
"Signature check failed", and **the README's troubleshooting entry for
`ecrecover did not match either parity` is now out of date.**

### 4.2 Both chains refuse an unfundable sale before signing

| Function | Chain | Asks |
|---|---|---|
| `evm_balance_ok()` | Ethereum, Polygon | `eth_getBalance` for gas (+ the value on a native sale), `balanceOf` over `eth_call` for a token |
| `tron_balance_ok()` | Tron | `/wallet/getaccount` for TRX, `balanceOf` via `/wallet/triggerconstantcontract` for a TRC-20, `/wallet/getaccountresource` for energy |

Both run at the first moment the payer is known — after the tap, before the
signature, before the broadcast. Nothing is spent if the answer is no.

Two rules they share:

- **A read that fails is not a refusal.** These improve a message; they do not
  gate payments. A terminal that stopped selling because one RPC read timed out
  would be worse than the problem being fixed.
- **Refusals name the asset**: "Not enough USDC on the card", "Not enough ETH
  for the network fee".

On Tron the fee test is deliberately narrow — it refuses only when TRX *and*
available energy are both zero. A TRC-20 burn can be paid out of a stake, so an
account with no TRX can still transact; pricing the burn would mean tracking a
network parameter, and getting it wrong refuses sales that would have settled.

### 4.3 One parser, saturating

Balances are `uint256` and the firmware compares them as `uint64`.
`eth_json_hex_quantity()` (`main/eth_json.h`, header-only) saturates at
`UINT64_MAX` rather than wrapping: over-reporting a balance only lets a doomed
sale reach the node that would have refused it anyway, whereas a wrapped value
would refuse a sale that is funded. 20 ETH is past 2^64 wei, so this is the
ordinary case and not a corner. Host-tested in `tests/units/test_eth_hex.cpp`.

---

## 5. What did not change

The card remains the trust anchor. The terminal has never held a private key
and still does not; it never sees a seed. This changes which account the
terminal asks the *network* about — not what the card signs, and not the
security model in [security-analysis.md](security-analysis.md). A fully
compromised terminal still cannot move funds without a cardholder tapping.

Every early exit between `card_connect()` and `card_sign()` closes the card
session; `card_sign()` closes it on its own paths. Seven exits, checked.

---

## 6. What is not proven yet

**No sale has been paid with a card other than the previously compiled-in one.**
That is the single test that demonstrates the change, and it needs a second
Cryptnox card at the terminal. Until then the firmware builds, the host suite
and the portal checks pass, and the image boots on hardware under Secure Boot
v2 — none of which exercises the path this document is about.

The balance refusals are likewise unexercised on hardware.

---

## 7. The open question

If the terminal is meant to be tied to one merchant card rather than to accept
customer cards, §4.1 should be reverted — and the funding check would move back
before the tap with it, since the payer would be known in advance again.

That is a product decision. The code supports either; this document exists so
the decision is made on purpose rather than inherited from an ordering.

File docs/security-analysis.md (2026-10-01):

# Security analysis

What this terminal is worth attacking for, who can reach it, what stops them,
and what does not. Written against the code in this repo — every claim below
names the file that implements it, so a reader can disagree with the code rather
than with this document.

Scope: the firmware. Not the card applet, not the merchant's Wi-Fi, not the
chains or the RPC providers.

---

## 1. What an attacker wants

| Asset | Why it matters | Where it lives |
|---|---|---|
| **Payout addresses** | Change one and every future payment goes to the attacker. This is the whole game. | NVS, `settings.cpp` (`K_PAY_ETH`/`K_PAY_TRX`, written in duplicate) |
| **Token contract addresses** | A wrong contract moves a different asset than the one on screen | NVS + `config.h` fallbacks |
| **What the operator believes** | A terminal that displays PAID on a failed payment is a free-goods machine | `ui_sale.cpp`, gated in `pay.cpp` (`settle_inflight`) |
| **Firmware** | Replace it and everything above is moot | `ota_0`/`ota_1` |
| **Card PIN** | Signing authority for the tap in progress | RAM only, wiped after use |
| **Wi-Fi credentials** | Lateral movement into the venue network | NVS (encrypted) |

**The most important thing on this list is what is not on it: private keys.**
The card signs; the terminal never holds a key and never sees a seed. A fully
compromised terminal cannot sign a transaction the cardholder did not tap for.
That single architectural decision removes the class of attack that would
otherwise dominate this document.

---

## 2. Trust boundaries

```
   ┌────────────────┐   NFC / I²C     ┌──────────────────────┐
   │ Cryptnox card  │◄───────────────►│                      │
   └────────────────┘  PIN verified   │                      │
                       before signing │                      │
   ┌────────────────┐   touch         │                      │
   │ Operator       │◄───────────────►│   ESP32 terminal     │
   │ (at the panel) │  admin code,    │                      │
   └────────────────┘  on-screen      │   secure boot v2     │
                       confirmations  │   flash encryption   │
   ┌────────────────┐   HTTP over     │   NVS encryption     │
   │ Browser        │◄───────────────►│                      │
   │ (config page)  │  the device's   │                      │
   └────────────────┘  own WPA2 AP    │                      │
                                      │                      │
   ┌────────────────┐   HTTPS +       │                      │
   │ RPC nodes      │◄───────────────►│                      │
   └────────────────┘  cert bundle    │                      │
                                      │                      │
   ┌────────────────┐   UART          │                      │
   │ Host / flasher │◄───────────────►│                      │
   └────────────────┘  signed images  └──────────────────────┘
```

The boundary that carries the most weight is **operator ↔ panel**. Every change
that can redirect money is confirmed on the terminal's own screen, by someone
physically in front of it — never in the browser alone. That is a deliberate
design choice and it is what makes the config page's weaker transport tolerable.

---

## 3. What stops an attacker today

### Firmware integrity

- **Secure Boot v2, RSA-3072.** `CONFIG_SECURE_BOOT_V2_ENABLED`,
  `CONFIG_SECURE_SIGNED_APPS_RSA_SCHEME` (`sdkconfig` 350–361). Verified at every
  boot — the boot log shows `secure_boot_v2: Signature verified successfully`.
- **Signed OTA.** The terminal never contacts GitHub, so it cannot judge a TLS
  chain to decide whether an image is genuine. It has exactly one test: an
  RSA-3072 signature checked by `esp_ota_end()` against a key compiled into the
  firmware already running (`ota.cpp:177`, rationale in
  `sdkconfig.defaults.release`). An unsigned image is refused, and the operator
  is told why (`ota.cpp:183`).
- **Downgrade is visible, not blocked.** `ota_version_cmp()`
  (`ota_version.h`) tells the operator "This is an OLDER version" in red
  (`ui_admin.cpp`), and they decide. Deliberate: blocking downgrades outright makes a
  bricked fleet unrecoverable.
- **Rollback verdict surfaced.** An update that installed, booted and was then
  reverted says so on the About tab rather than silently reading as the old
  version (`ota_last_update_failed()`).

### Data at rest

- **Flash encryption** (`CONFIG_SECURE_FLASH_ENC_ENABLED`) and **NVS
  encryption** with a dedicated `nvs_keys` partition — visible at boot as
  `nvs_sec_provider: NVS Encryption`.
- **Payout addresses stored in duplicate** and cross-checked, so a single
  corrupted NVS entry cannot silently redirect funds (`settings.cpp`,
  `dual_get`/`dual_set`).
- **Dead secrets erased.** A self-signed TLS identity from an earlier build is
  actively deleted from NVS on boot rather than left to rot
  (`provision.cpp:225–238`), with an honest note that NVS deletes logically and
  this closes the NVS read, not a raw flash dump.
- **Signing keys are not in this repo.** `secure_keys/` is untracked —
  confirmed with `git ls-files`.

### The config page

- **The admin code is never typed into the browser.** It is entered on the
  panel; that is what proves the person is standing in front of the terminal
  (`provision.cpp`, the authorise section).
- **128-bit session token**, hex, from the hardware RNG, compared in constant
  time via `CW_Utils::secure_compare` (`provision.cpp:376–388`, token minted at
  `provision.cpp:1307`). The code notes the RNG is only a true one once the RF
  clock is running, and seeds accordingly (`provision.cpp:175`, `1815`).
- **Every value that matters is confirmed on the panel.** The browser can only
  *propose* a payout address or a contract; a human accepts it on the device's
  own screen (`provision.cpp`, `ui_setup.cpp` accept flow). This is what contains a
  compromised browser.
- **Session expiry and clear refusals**: `503` once the window closes, `401`
  when unauthorised, both with plain-language messages.
- **The page runs on the device's own AP**, not the venue LAN — which is why it
  no longer carries TLS at all (see finding **F3**).

### Payment correctness

- **PIN verified before signing**, not after (commit `82efc6d`).
- **Integrity gates** around every decision that ends in PAID: complement-encoded
  sentinels (`bool32`, `pos_verdict_t`) that a single flipped bit cannot forge,
  asserted at compile time (`hardening.h:50–55`), with `address_consistent()`
  re-checked before calldata, before signing and before display
  (`sign_and_broadcast` in `pay_evm.cpp`, `sign_and_broadcast_tron` in
  `pay_tron.cpp`, the confirm step in `main.cpp`, `settle_inflight` in `pay.cpp`).
- **Anomalies are counted in NVS**, not just logged, so a pattern survives a
  power cycle (`pos_handle_anomaly()`, `hardening.cpp`).
- **Address validation** on every entry path: base58 + checksum
  (`addr_check.h`), EIP-55 (`eth_addr.cpp`), Tron (`tron_tx.cpp`).
- **Clock hardening.** SNTP alone is spoofable by whoever runs the network, so
  the HTTPS response `Date` header is used to corroborate it and a skew beyond
  `CLOCK_SKEW_MAX_S` refuses the transaction (`https_post.cpp:111–131`). Without
  network time at all, the terminal declines rather than guessing
  (`UI_EVENT_AMOUNT_CONFIRMED` in `main.cpp`).
- **The node is not trusted for what gets signed.** Tron: the node-built
  transaction is decoded field by field (`tron_tx.cpp`) — exactly one contract of
  the expected type, byte-exact parameters, no memo / extra fields, bounded
  expiration, exact fee limit — before the card signs its `txID`. EVM: the
  transaction is built and hashed on the device, the recovery bit is computed
  locally (`eth_sig.cpp`), and a receipt only counts when it is for that hash, to
  the expected contract, with a `Transfer` log to the payee for exactly the
  amount (`eth_json_receipt_check`).
- **TLS with the ESP-IDF certificate bundle** for all RPC traffic
  (`https_post.cpp`). This is **not pinning**: any CA in the ~150-entry bundle is
  accepted. A deployment can pin an endpoint by defining `RPC_CA_CERT_PEM`,
  `POLY_CA_CERT_PEM` or `TRON_CA_CERT_PEM` in `config.h`; none are defined by
  default, and boot logs every endpoint that is left unpinned.

### Build and process

- **CodeQL** (`.github/workflows/codeql.yml`) and **cppcheck + clang-tidy**
  (`misra_check.yml`) are configured to run on every push — but both jobs are
  currently failing and have been for at least a month, so neither is actually
  protecting anything. See **F6**, which is why this bullet cannot be counted as
  a mitigation today.
- **Host tests** for the security-relevant pure logic — address checks,
  hardening sentinels, Tron transaction decoding, receipt checks, version
  comparison, RPC error mapping — runnable without hardware
  (`bash scripts/checks.sh`), and run by CI (`.github/workflows/tests.yml`).
- **Quiet boot in release**: `CONFIG_LOG_DEFAULT_LEVEL_NONE`, so nonces and tx
  hashes are not echoed over UART on a production unit.

---

## 4. Findings

Ordered by what I would fix first. None of these is a break of the payment path;
the first is a process gap that would undo much of section 3.

### F1 — A production unit built with the dev config is not a secure unit
**Severity: high (process, not code).**
This repo's checked-in `sdkconfig` has
`CONFIG_SECURE_FLASH_ENCRYPTION_MODE_DEVELOPMENT=y` and
`CONFIG_SECURE_INSECURE_ALLOW_DL_MODE=y`. The board says so itself at every
boot: `flash_encrypt: Flash encryption mode is DEVELOPMENT (not secure)`. In
that mode the UART download path can still encrypt and decrypt, so an attacker
with the device in hand and a cable can read out flash — including NVS, and so
the payout addresses and Wi-Fi credentials.

This is *correct* for the bench and `sdkconfig.defaults.release` exists to fix
it, is well documented, and switches to `RELEASE` mode plus signed OTA. The risk
is entirely that someone ships a unit without layering it.

**Fix:** make it impossible to do by accident rather than by discipline — a
release build script that always passes the three overlays in order, and a
runtime refusal (or at minimum a permanent on-screen banner) when a build
reports `DEVELOPMENT` mode. A terminal should be able to tell the operator it is
not a secure unit.

### F2 — ROM UART download mode is left enabled
**Severity: medium, and deliberate.**
`CONFIG_SECURE_DISABLE_ROM_DL_MODE` is off, documented as a trade-off in
`sdkconfig.defaults.release`: enabling it makes recovery OTA-only. With RELEASE
flash encryption the download path can no longer decrypt, so this is much
narrower than F1 — but it keeps a physical foothold open.

**Fix:** none required today. Revisit once the signed-OTA path has enough field
history to be the only recovery route. The decision and its reason are already
written down, which is the important part.

### F3 — The config page is plain HTTP
**Severity: medium.**
`httpd_start()` with `HTTPD_DEFAULT_CONFIG()` (`provision.cpp:1833`, `1889`) —
no TLS. The mitigation is real: the page is served on the terminal's **own**
WPA2 AP with a randomly generated password, not on the venue LAN, and the old
self-signed identity is now actively erased. But everyone who has that AP
password shares the segment, and over it travel the session token and — during
setup — the venue Wi-Fi password.

**Fix:** the cheap and effective half is scope reduction, most of which is
already done. If this needs closing, a self-signed cert re-introduces the
browser warning that made it worse last time; the better direction is to stop
sending the Wi-Fi password over the page at all (enter it on the panel) and
accept the token exposure, which on its own cannot move money.

### F4 — No transaction record on the device
**Severity: low for security, real for disputes.**
Nothing is persisted about a completed payment: no log, no receipt, no counter.
I grepped for it — there is no tx history in NVS and the Tx tab shows
configuration, not past payments. There is therefore no forensic trail on the
device after an incident, and no way to reconcile the terminal against the chain
without knowing what to look for.

**Fix:** a bounded NVS ring of the last N payments (timestamp, asset, amount, tx
hash). Bounded because NVS write endurance is finite. Note this is
privacy-relevant if the payer's address is included — that is a product
decision.

### F5 — Admin code strength is the merchant's choice
**Severity: low, mitigated.**
`ADMIN_CODE_MIN` was 4 digits (`ui_internal.h`). Against that: attempts are counted
**in NVS**, so the escalating lockout survives a power cycle and cannot be reset
by pulling the plug (`admin_penalty_ms`, `s_admin_lock_*`), and input is blocked
for the penalty window (`admin_lock_remaining_s`, `ui_admin.cpp`). Shoulder-surfing at a counter remains
the more realistic attack, and no PIN policy fixes that.

**Fix (done):** new codes need 6 digits and the penalty keeps doubling up to an
hour per attempt; a code stored under the old 4-digit minimum still unlocks, so
existing units are not forced mid-life.

---

### F6 — The automated scanning has never actually run
**Severity: high (process).**
Both security workflows fail on every push, and have since at least
2026-09-04 — checked with `gh run list`. The repo looks scanned and is not.

- **CodeQL** dies in its build step, so `Analyse` never executes and no results
  are ever uploaded (`CodeQL job status was configuration error`). Cause:
  `tests/units/test_networks.cpp` includes `config.h`, which is gitignored
  (`.gitignore:2`) because it holds real contract and payout addresses — so the
  CI checkout does not have it. `fatal error: config.h: No such file or
  directory`.
- **cppcheck** fails on two real diagnostics with `--error-exitcode=1`, and
  because it is the first step the clang-tidy step below it never runs either:
  - `main/main.cpp:784` — `nullPointerRedundantCheck` on
    `native ? to->addr : token->addr`. Almost certainly a false positive:
    `native` comes from `chain_is_native_evm()` and the dereference is on the
    non-native branch, which cppcheck cannot prove. Needs an
    `// cppcheck-suppress` with a reason, not a code change.
  - `main/settings.cpp:509` — `duplicateExpressionTernary` on
    `m ? "0x" ADDR_USDC_MAIN : "0x" ADDR_USDC`. The two macros are genuinely
    different addresses in `config.h`, so this is likely an artefact of
    `--force` exploring a configuration where neither is defined — but it sits
    on the line that decides which contract the terminal calls, so it deserves
    a real look rather than a blanket suppression.

**Fix:** generate `main/config.h` from `config.template.h` as a CI step before
either job builds — the template's placeholder values compile fine and no real
address enters CI. Then triage the two cppcheck diagnostics so the job goes
green and stays meaningful. A red pipeline that everyone has learned to ignore
is worse than no pipeline, because it is quoted as assurance.

---

## 5. What this analysis does not cover

Stated plainly so nobody reads more assurance into it than it carries:

- **No penetration test was performed.** Nothing here was attacked; this is code
  and configuration review.
- **The card applet is out of scope** — the terminal's security depends on it
  refusing to sign without a verified PIN, which is asserted, not verified here.
- **No side-channel or fault-injection analysis** (glitching the integrity
  gates, EM analysis of the NFC exchange).
- **The RPC providers are trusted for chain state, not for what is signed.** A
  lying node (or anyone holding a certificate from a bundled CA, since endpoints
  are unpinned by default) cannot get the card to sign a different transfer, but
  it can still fabricate a receipt for a transaction that never landed, or report
  a balance that is not there. The on-chain record is the truth, and the
  terminal's own display is not authoritative for settlement.
- **Supply chain** — the ESP-IDF, LVGL and managed component versions are pinned
  (`dependencies.lock`) but not audited.

An external review should start at F1 and F6. F1 decides whether everything in
section 3 is actually switched on in the field, and F6 is why nobody would be
told if it stopped being true.

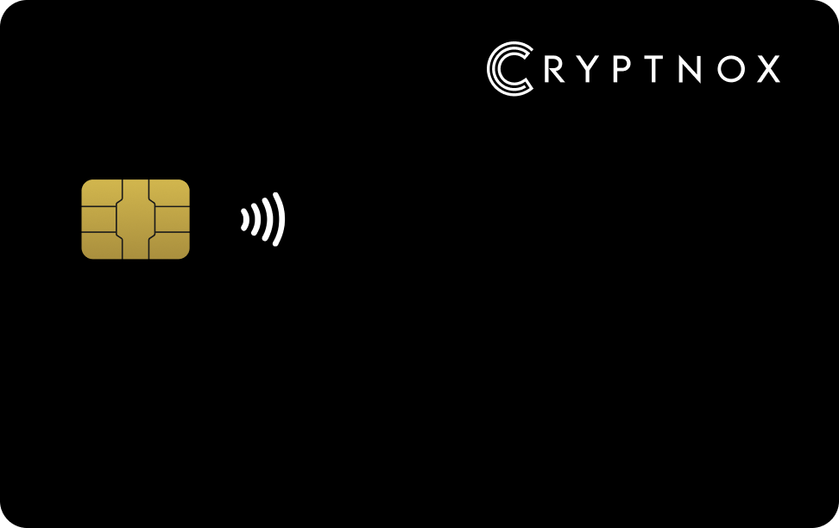
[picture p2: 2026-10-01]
assets/cryptnox_card.png

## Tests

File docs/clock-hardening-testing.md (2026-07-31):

# Clock hardening — test procedure

Verifies the three defences that make TLS certificate dates actually count:

| # | Defence | Where |
|---|---|---|
| 1 | `CONFIG_MBEDTLS_HAVE_TIME_DATE=y` — enforce `notBefore`/`notAfter` | `sdkconfig.defaults` |
| 2 | Reject a synced clock earlier than the firmware build stamp | `main/net.cpp` — `build_time_floor()` |
| 3 | Corroborate the clock against the authenticated HTTP `Date` header | `main/eth_rpc.cpp` — `clock_corroborated()` |

Shared calendar arithmetic lives in `main/civil_time.{h,cpp}` — a pure unit with
no IDF dependencies, so it builds and self-checks on the host.

**Why all three:** `HAVE_TIME_DATE` alone bases a trust decision on a clock
supplied over unauthenticated NTP. Items 2 and 3 constrain that clock, and they
catch *different directions* of error — see the note under test 4.

---

## Prerequisites

```powershell
cd C:\Cryptnox\cryptnox-pos
. C:\esp\v5.5.4\esp-idf\export.ps1     # puts idf.py on PATH
```

Builds go through `scripts\idf-build-flash.bat COM3` (`idf.py` will not run
under Git Bash). Device assumed on COM3.

---

## Test 0 — Date arithmetic (host, no device)

The cheap gate. Run this on any change to `civil_time.cpp`.

```powershell
cd fuzz; g++ -std=c++14 -o tct test_civil_time.cpp; .\tct.exe; cd ..
```

Expect `civil_time: all checks passed`. Covers leap years (2024 / 2100 / 2000),
month boundaries across a decade, both parsers, and malformed-input rejection.
Reference epochs are cross-checked against Python's `calendar.timegm`.

Also available as a CMake target: `test_civil_time` in `fuzz/CMakeLists.txt`.

## Test 0b — Confirm date checks are compiled in

```powershell
Select-String MBEDTLS_HAVE_TIME_DATE build\config\sdkconfig.h
```

Must print `#define CONFIG_MBEDTLS_HAVE_TIME_DATE 1`.

> **`sdkconfig` is gitignored and an existing value there beats
> `sdkconfig.defaults`.** Anyone who pulls without deleting their `sdkconfig`
> gets a build where item 1 silently does nothing, and items 2–3 guard a check
> that was compiled out. If this prints nothing, delete `sdkconfig` and rebuild.

---

## Test 1 — Normal boot → unchanged

No code changes.

```powershell
.\scripts\idf-build-flash.bat COM3
idf.py -p COM3 monitor        # Ctrl+] to exit
```

Expect:

```
I net: System time synced via SNTP (epoch 17854...)
I eth_rpc: Nonce: 786
I cryptnox_pos: Ready
```

Then run one real payment end-to-end.

The `Date` corroboration logs at DEBUG on success, so a silent pass is the
expected result — a `refusing` or `no Date header` line here is a bug.

*Leaf renewals still accepted* is implied rather than observed: `RPC_CA_CERT_PEM`
pins the GTS WE1 intermediate, so server-side leaf rotation is transparent.
**Re-pin before its `notAfter`, Feb 20 14:00:00 2029 GMT.**

---

## Test 2 — Deliberately wrong clock → TLS refused, boot reports it

Temporary scaffold. In `main/net.cpp` add `#include <sys/time.h>` at the top,
and insert immediately **before** the `/* SNTP is unauthenticated` comment:

```c
{ struct timeval tv; tv.tv_sec = 1893456000; tv.tv_usec = 0;   /* 2030-01-01 */
  (void)settimeofday(&tv, NULL); ESP_LOGW(TAG, "TEMP: clock forced to 2030"); }
```

2030 is past the pinned intermediate's `notAfter`, and is *forward* of the build
stamp so it deliberately passes the item-2 floor — this isolates item 1.

Flash and monitor. Expect:

```
E esp-tls-mbedtls: mbedtls_ssl_handshake returned -0x2700      (x3 retries)
E esp-tls: Failed to open new connection
E eth_rpc: HTTP open: ESP_ERR_HTTP_CONNECT
E cryptnox_pos: RPC unreachable or clock rejected at boot
```

`-0x2700` is `MBEDTLS_ERR_X509_CERT_VERIFY_FAILED`.

### Control: prove item 1 is load-bearing

Set `# CONFIG_MBEDTLS_HAVE_TIME_DATE is not set` in `sdkconfig`, rebuild, and
re-run. **The handshake succeeds on the expired certificate** — this is the bug
the whole change exists to fix. Restore the flag afterwards and confirm test 0b.

---

## Tests 3 + 4 — one rig, both items

Test 4's back-dated case *is* test 3, exercised over the real SNTP wire path, so
run them together rather than forcing the clock for test 3.

Remove the test-2 scaffold first. Then two temporary edits:

**`main/net.cpp`** — point SNTP at your machine (use your own Wi-Fi IPv4, from
`ipconfig`; the device must be on the same subnet):

```c
esp_sntp_config_t config = ESP_NETIF_SNTP_DEFAULT_CONFIG_MULTIPLE(1,
    ESP_SNTP_SERVER_LIST("192.168.1.39"));
```

**`CMakeLists.txt`** — before `project(cryptnox_pos)`:

```cmake
idf_build_set_property(COMPILE_DEFINITIONS "SNTP_PORT=11123" APPEND)
```

The port override is what lets this run **without Administrator**: `w32time`
holds UDP/123 exclusively, and freeing it needs elevation. lwIP guards
`SNTP_PORT` with `#if !defined`, so a global define moves both the client's
local bind and its destination. Nothing else about the SNTP path changes.

Flash, then run the hostile server — ordinary shell, one case per board reset:

```powershell
python -u tools\spoof_ntp.py --days -200  --bind 192.168.1.39 --port 11123   # Test 3
python -u tools\spoof_ntp.py --minutes 30 --bind 192.168.1.39 --port 11123   # Test 4
```

### Test 3 — clock forced before the build date → sync refused

```
E net: SNTP time 1768125504 precedes firmware build floor 1785344045 - refusing (spoofed NTP?)
E net: SNTP time 1768125508 precedes firmware build floor 1785344045 - refusing (spoofed NTP?)
E net: SNTP time 1768125508 precedes firmware build floor 1785344045 - refusing (spoofed NTP?)
E cryptnox_pos: SNTP time sync failed
```

The floor is the build stamp minus 86400 s. `__DATE__`/`__TIME__` are the build
machine's *local* time read back as UTC, so a day of slack absorbs any TZ
offset; it costs an attacker nothing, since reviving an expired certificate
needs weeks of back-dating.

### Test 4 — simulated NTP spoof → detected

```
I net: System time synced via SNTP (epoch 1785407390)
E eth_rpc: clock off by 1800 s vs server (local 1785407393, server 1785405593) - refusing (spoofed NTP?)
E cryptnox_pos: RPC unreachable or clock rejected at boot
```

The server prints `lied to 192.168.1.40: ...` when the device polls it. If it
stays silent the device is not reaching you — check Windows Firewall for
`python.exe` on Private networks, and that the bind IP is still current.

> **Run both cases.** They exercise different defences: back-dating trips the
> item-2 floor at sync time and never reaches TLS; forward skew passes the floor
> and is caught later by the item-3 `Date` header. Either one alone leaves half
> the feature untested.

---

## Cleanup

Revert the server list, the `SNTP_PORT` line, and any clock override, then:

```powershell
Select-String -Path main\*.cpp,CMakeLists.txt -Pattern "TEMP|192\.168|SNTP_PORT|settimeofday"
```

Should return nothing. Rebuild, flash, re-run test 1.

---

## Notes

- **Boot now requires a reachable RPC endpoint.** `app_main` makes one
  `eth_rpc_get_nonce()` call after the sync loop: it proves reachability and is
  the first request whose authenticated `Date` can contradict SNTP. Three
  retries, then the terminal refuses to start. Without it a forward-dated clock
  reaches `Ready` and only fails mid-payment. Costs ~4 s of boot.
- **A missing or unparseable `Date` header skips the check**, it does not fail
  the request. The response already passed pinned-CA TLS, so an absent header
  means the provider omitted it; failing payments over that would be a
  self-inflicted outage. An attacker cannot induce this without breaking TLS.
- **On mismatch the firmware refuses rather than adopting the header's time**,
  so one wrong provider clock can never silently redefine "now".
- `esp_http_client_get_header()` reads *request* headers and can never return
  the server's `Date`. Response headers are only reachable via
  `HTTP_EVENT_ON_HEADER` — see `http_event_cb()` in `main/eth_rpc.cpp`.

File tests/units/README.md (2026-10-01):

# Unit tests — cryptnox-pos

Host-side unit tests. Each is a single translation unit that `#include`s the
production sources directly (same pattern as [`fuzz/`](../../fuzz)), so a test
can never drift from the firmware and no build system is required.

| Test | Under test |
|---|---|
| `test_eth_addr` | `main/eth_addr.cpp` — hex parsing + EIP-55, both ways |
| `test_hardening` | `main/hardening.h` — decision-integrity gate |
| `test_tron_tx` | `main/tron_tx.cpp` — Tron varints, TransferContract + TRC-20 checks, envelope |
| `test_prov_form` | `main/form_parse.h` — config-portal urlencoded field extraction |
| `test_addr_check`  | `main/addr_check.h` — structural Tron address check |
| `test_json_out` | `main/json_out.h` — escaping an SSID into a JSON response |
| `test_ota_version` | `main/ota_version.h` — update vs downgrade ordering |
| `test_card_status` | `main/card_status.h` — is the tapped card initialised and seeded |
| `test_chain` | `main/settings.h` — which chain selections are Tron, which Polygon |
| `test_rpc_error` | `main/rpc_error.h` — a node's refusal turned into an operator instruction |
| `test_networks` | `main/config.h` — every contract parses (EIP-55) and mainnet/testnet chain ids differ |
| `test_assets` | `main/assets.h` — one complete descriptor row per asset |
| `test_touch_cal` | `main/touch_cal.h` — calibration arithmetic and its refusals |
| `test_eth_hex` | `main/eth_json.cpp` — JSON-RPC QUANTITY → balance, no silent wrap |
| `test_eth_receipt` | `main/eth_json.cpp` — a receipt counts only for our tx, contract, payee and amount (needs cJSON) |
| `test_eth_sig` | `main/eth_sig.cpp` — the recovery bit, computed locally (needs mbedTLS) |
| `test_civil_time`  | `fuzz/test_civil_time.cpp` — date arithmetic for the clock checks |
| `test_eth_rlp` | `main/eth_rlp.cpp` — EIP-1559 bytes, unsigned and signed, against eth-account |
| `test_money` | `main/money.h` — keypad cents, units to wei, fees, funds check, USDC calldata |
| `test_settings_rules` | `main/settings_rules.h` — time zone, fee bounds, admin digest, address form |

`test_eth_receipt` and `test_eth_sig` link against ESP-IDF's own cJSON and
mbedTLS sources; `checks.sh` finds them through `IDF_PATH` and skips the two
tests when it is unset.

Run all of them, plus the config portal page checks, with:

```sh
bash scripts/checks.sh            # add --build for the firmware build too
```

Or one at a time, from the repo root (any C++14 compiler):

```sh
for t in test_eth_addr test_hardening test_tron_tx test_prov_form test_addr_check \
         test_json_out test_ota_version test_card_status test_chain \
         test_rpc_error test_networks test_assets test_touch_cal test_eth_hex \
         test_eth_rlp test_money test_settings_rules; do
  g++ -std=c++14 -Wall -Imain -Icryptnox-sdk-esp32/cryptnox-sdk-cpp \
      tests/units/$t.cpp -o $t && ./$t || exit 1
done
```

Assertions only — a test either prints `... OK` and exits 0, or aborts.

## The config portal page

The page is a pair of C string literals, so the compiler proves the C is valid and
nothing proves the HTML or the JavaScript is. Two checks in `tools/` cover it, and
`scripts/checks.sh` runs both:

| | |
|---|---|
| `check_portal_page.py` | extracts the literals, runs the script through `node --check`, and asserts every element id is referenced from both sides |
| `test_portal_render.js` | drives `render()` against each `(mode, step, authed, pending)` the device can report, asserting which sections are visible |

The second one matters more than it looks: which sections show is a hand-written
pile of booleans, it decides whether setup can be completed at all, and a mistake
there is invisible until somebody is standing in front of a blank phone.

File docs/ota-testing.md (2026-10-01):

# Testing firmware updates over Wi-Fi

Test plan for the browser-mediated OTA path added in `main/ota.cpp`. What the
feature is and why it has this shape: [`docs/ota.md`](ota.md).

Four layers, cheapest first. Do them in order — a failure at layer 1 makes the
rest meaningless, and §4 is the one that decides whether this feature is safe to
put in the field.

1. **Host** — version ordering, no hardware.
2. **Bench** — `curl` against the endpoints. Proves every rejection path without
   ever installing anything.
3. **Real update** — install a second build, from a browser, end to end.
4. **Rollback** — install a *deliberately broken* build and watch the terminal
   come back on the old one.

---

## 0. Prerequisites

### The first flash is not optional

`partitions.csv` changed. **The partition table is never rewritten by an update**,
so a unit carrying the old single-app table has to be flashed over serial once
before any of this works. Find the port, then flash:

```bash
powershell -NoProfile -Command "[System.IO.Ports.SerialPort]::GetPortNames()"
cmd //c "C:\Cryptnox\cryptnox-pos\scripts\idf-build-flash.bat COM7"
"C:/Users/Yann/.espressif/python_env/idf5.5_py3.14_env/Scripts/python.exe" \
    scripts/serial_tail.py COM7 20
```

`nvs` and `phy_init` keep their old offsets (0x9000, 0xF000), so **stored
settings survive** the table change on a plain build — admin code, Wi-Fi, payout
addresses all come back. Two exceptions:

| Situation | Consequence |
|---|---|
| Flash-encryption build | `nvs_keys` moved (0x310000 → 0x12000). The encrypted NVS is unreadable; re-provision from scratch. |
| Anything odd after the change | `idf.py -p COM7 erase-flash` and start clean, rather than debugging a half-migrated NVS. |

### Confirm the table and the config actually took

```bash
grep -n "BOOTLOADER_APP_ROLLBACK" sdkconfig
grep -n "define CONFIG_BOOTLOADER_APP_ROLLBACK_ENABLE" build/config/sdkconfig.h
```

**Pass:** `=y` and `1`. `sdkconfig` is gitignored and **wins over
`sdkconfig.defaults`** — a stale `# CONFIG_BOOTLOADER_APP_ROLLBACK_ENABLE is not
set` line leaves §4 silently doing nothing while everything else looks fine.
Delete `sdkconfig` and rebuild, or flip the line by hand.

```bash
grep -n "binary size" <build log>       # expect: Smallest app partition is 0x1f0000
```

**Pass:** the app fits with headroom to spare (~19% at the time of writing). Under
5% free, stop and shed LVGL fonts before continuing — a slot that cannot hold the
*next* build makes OTA useless.

### Reading the log

Every check below quotes lines from the `ota` tag. They only exist on a dev
build: `sdkconfig.defaults.release` sets `CONFIG_LOG_DEFAULT_LEVEL_NONE`, so on a
release image the panel and the browser are the only instrumentation.

---

## 1. Host tests

```bash
for t in test_eth_addr test_hardening test_tron_tx test_prov_form \
         test_addr_check test_json_out test_ota_version; do
  g++ -std=c++14 -Wall -Imain -Icryptnox-sdk-esp32/cryptnox-sdk-cpp \
      tests/units/$t.cpp -o $t && ./$t || exit 1
done
```

`test_ota_version` covers `main/ota_version.h`: numeric (not lexicographic)
ordering, optional leading `v`, absent components as zero, ignored `-rc1`/`+sha`
suffixes, clamped overflow, and the 32-byte boundary of
`esp_app_desc_t::version` pinned from both sides. All five must print `OK`.

### 1.1 The browser must agree with the panel

The page carries its own copy of the comparison (`cmp()` in the `<script>`), and
it decides which button the operator is offered. Open the update page (§2), then
in the browser console:

```js
[['1.2.0','1.10.0',-1],['9.0.0','10.0.0',-1],['v1.2.3','1.2.3',0],
 ['1.2','1.2.0',0],['1.2.3-rc1','1.2.3',0],['','1.0.0',-1]]
  .filter(([a,b,w]) => Math.sign(cmp(a,b)) !== w)
```

**Pass:** `[]`. Anything listed is a case where the browser would label a
downgrade as an update — the panel would still catch it in red, but the two
disagreeing means one of them is wrong.

---

## 2. Bench tests — `curl` against the endpoints

Finish setup so the terminal is joined to a network with an admin code set. Then
**Settings → About → Update** (or Wi-Fi → **Configure** — the same page). The panel
shows a QR code and the URL; the log agrees:

```
W (nnnn) prov: admin page up at https://192.168.1.34/ for 15 min
```

The transport is HTTPS with the terminal's own self-signed certificate, so every
`curl` here needs `-k`. Authorisation is a session token, not an admin-code header —
see [config-portal.md](config-portal.md) and §2.4 of
[testing-provisioning.md](testing-provisioning.md), which is where the
authorisation itself is tested. Get a token the same way:

```bash
T=https://192.168.1.34
curl -sk -X POST $T/api/auth        # then enter the admin code ON THE PANEL
H="X-Prov-Token: $(curl -sk -X POST $T/api/auth)"
```

**Fail before you start:** if the panel says the terminal has to be on a Wi-Fi
network while it plainly is, the DHCP lease has not landed yet
(`not on a network - nothing could reach the config page`). Wait and retry.

### 2.1 The page and the state endpoint

```bash
curl -sk -H "$H" $T/api/state
curl -sk -o /dev/null -w '%{http_code} %{size_download}\n' $T/
```

**Pass:** the JSON carries `"mode":"admin"`, `"authed":true`, `"version":"v1.0.0-91-gc10d526"` (your tag, count and hash),
`"win":15`, and the stored addresses and contracts. `version` must match the About
tab and the `Firmware v…` line the build prints. The page is a `200` of roughly 9 kB.

### 2.2 Authorisation

```bash
head -c 400000 /dev/urandom > /tmp/junk.bin
curl -ski -X POST --data-binary @/tmp/junk.bin $T/api/ota | head -1   # no token
curl -ski -X POST -H 'X-Prov-Token: 00000000000000000000000000000000' \
     --data-binary @/tmp/junk.bin $T/api/ota | head -1                # wrong token
```

**Pass:** both `401`, body "This browser is not authorised" — and **no**
`receiving ... bytes` line. The flash must not be touched before the token is
checked.

Note what is *not* being tested here any more: there is no admin code on the wire
to guess, so there is no rate limit to exercise on this endpoint. The guessing
budget lives on the panel keypad, and §2.4 of the provisioning plan is where it is
tested.

### 2.3 Size rejection

```bash
head -c 1000 /dev/urandom > /tmp/tiny.bin
head -c 2200000 /dev/urandom > /tmp/huge.bin
curl -sk -X POST -H "$H" --data-binary @/tmp/tiny.bin $T/api/ota
curl -sk -X POST -H "$H" --data-binary @/tmp/huge.bin $T/api/ota
```

**Pass:** `too small to be firmware` and `larger than the firmware slot`. Again no
`receiving` line — neither reaches `esp_ota_begin()`.

### 2.4 A plausible-sized file that is not firmware

This is the check that proves `esp_ota_end()` is doing its job:

```bash
curl -sk -X POST -H "$H" --data-binary @/tmp/junk.bin $T/api/ota
curl -sk -H "$H" $T/api/state
```

**Pass:** the upload runs (`receiving 400000 bytes into 'ota_1'`), then
`image rejected: ESP_ERR_OTA_VALIDATE_FAILED`, and the response says the image is
not valid firmware or is not signed with a trusted key. `staged` stays `false`,
and **the panel shows nothing** — a rejected image never reaches the operator.

Then take a payment. The terminal must be completely unaffected by having had
400 kB of noise written into its spare slot.

### 2.5 A truncated upload

```bash
# throttled, then cut off part-way: ~600 kB of a 1.6 MB image arrives
curl -sk -X POST -H "$H" --data-binary @build/cryptnox_pos.bin \
     --limit-rate 200k --max-time 3 $T/api/ota
curl -sk -H "$H" $T/api/state
```

**Pass:** log shows `upload aborted at <n>/<total> bytes`, `staged` is `false`,
nothing on the panel. Then repeat §2.4 or §3 successfully — a dropped upload must
not wedge the slot for the next one.

### 2.6 One at a time

Upload a real image (§3) so something is staged, and *before* touching the panel:

```bash
curl -sk -X POST -H "$H" --data-binary @build/cryptnox_pos.bin $T/api/ota
```

**Pass:** `409`, "An update is already waiting to be accepted on the terminal
screen." Two images cannot occupy one slot.

### 2.7 The window closes

Open the window, note the time, and leave the terminal alone for 15 minutes
(`PROV_WINDOW_MIN`).

```bash
curl -sk -o /dev/null -w '%{http_code}\n' -X POST -H "$H" \
     --data-binary @/tmp/junk.bin $T/api/ota
curl -sk -o /dev/null -w '%{http_code}\n' $T/
```

**Pass:** `503` from the upload endpoint, log `config portal down`, and **the card
on the panel disappears by itself**. The terminal must then accept a payment
normally.

That last part matters more than it looks: these modals swallow every touch, so a
card left behind after its window closed is a terminal that cannot take money
until somebody power-cycles it.

Also check the case where the operator has *left* the card — enter the admin code
so the panel moves to the settings page, then wait the window out. The server must
still stop; the shutdown is not gated on anybody looking at a modal.

For the impatient version, tap **Done** instead and check the same:
`config portal down`, card gone, `curl -k $T/` refused.

---

## 3. The real update, from a browser

Make a second build to install:

```bash
# The version is <tag>-<count>-g<hash> from git. POS_VERSION_TAG replaces the tag
# part for a test build; touch makes CMake pick it up.
touch CMakeLists.txt
POS_VERSION_TAG=v1.0.1 cmd //c "C:\Cryptnox\cryptnox-pos\scripts\idf-build.bat"
cp build/cryptnox_pos.bin /tmp/1.0.1.bin
touch CMakeLists.txt            # next build is back on the real tag, for the downgrade check
```

### 3.1 The file picker — the only path there is

1. Open Update on the panel, then scan the QR code to join the terminal's own
   setup network; the page opens itself.
2. The panel asks for the admin code — enter it *there*. Then press **Browse**
   and pick `/tmp/1.0.1.bin`. Picking it starts the transfer: there is no second
   confirm button.
3. Watch the percentage climb. Expect `receiving 1653... bytes into 'ota_1'`.
4. Browser says *"Version 1.0.1 received and verified. Accept it on the terminal
   screen…"*; log says `staged 1.0.1 in 'ota_1' - awaiting on-screen accept`.
5. **The panel raises a card reading "New firmware / 1.0.1"** with Install and
   Discard. Nothing has rebooted.

**Fail:** any path where the terminal reboots into new firmware without a tap on
the panel. A browser may propose; only the panel may install.

### 3.2 Discard

Tap **Discard** first, on purpose.

**Pass:** the card closes, the window closes with it, and `/api/state` still
reports `1.0.0` in `ota_0`. Reboot the terminal — still `1.0.0`. A refused image
must not install itself later.

### 3.3 Install

Upload again, tap **Install**.

```
W (nnnn) ota: installing 1.0.1 from 'ota_1' - rebooting
```

**Pass, after the reboot:**

- The panel greets you — the welcome screen, reading **Updated to 1.0.1.** — and
  **Start** opens the amount screen. Power-cycle from there and the greeting must
  *not* come back: it is the first boot on a new image that earns it, not every
  boot.
- About tab reads `1.0.1`.
- `curl -sk -H "$H" $T/api/state` → `"version":"1.0.1","slot":"ota_1"` — the slot has
  flipped.
- The log carries `ota: update to 1.0.1 confirmed - rollback cancelled`, and it
  appears **after** `cryptnox_pos: Ready`, not before.
- Take a payment. The card, the panel, the RPC and the payout address all behave
  exactly as before.

**Fail:** `could not confirm this image - it WILL roll back` means the next reset
throws the update away. The terminal works right now and will be a different
version tomorrow — treat it as a blocker.

Install a third build (bump to `1.0.2`) and check the slot alternates back to
`ota_0`. A terminal that only ever writes one slot is not doing OTA.

### 3.4 The downgrade warning

Upload the original `1.0.0` image onto the `1.0.1` terminal.

**Pass:** the card reads **"Go back to firmware / 1.0.0"** and the body text
begins *"This is OLDER than the firmware installed now."* in red. The image is
signed exactly as well as the new one, so this warning is the only thing standing
between an operator and being talked into a build with a known fault.

Install it and confirm the terminal comes back on `1.0.0`, then go forward again.

### 3.5 The answer that never arrives

The upload is the one request that takes minutes over a SoftAP, so it is the one
that can lose its answer. Pull the phone out of range (or turn its Wi-Fi off)
*after* the progress line reaches 100% but before the browser says anything.

**Pass:** *"Not installed: the file went across but the terminal did not answer -
if a version is showing on its screen it arrived, accept it there"* — and the
panel is indeed showing 1.0.1 waiting to be accepted. Kill the connection
*during* the transfer instead and the message is the flat *"the connection to the
terminal dropped"*, with nothing on the panel. Two different events, two
different sentences: an operator told "not installed" about firmware that is at
that moment on the panel uploads the same image three times.

### 3.6 The settings wipe

New firmware clears the terminal's stored settings, so a unit that has just been
updated is an unowned unit: no admin code, no Wi-Fi, no payout address, and the
setup wizard in front of whoever is standing at it.

**What counts as "new" is `BUILD_ID`: the build sets it to
`git rev-list --count --first-parent HEAD` (project `CMakeLists.txt`), so every
new commit has a new one and nobody can edit it back.** The running build stamps it into NVS; a boot that finds any
*other* value there — or none — erases the partition, first thing in
`app_main()`, before anything has opened NVS. It therefore fires the same way
however the firmware arrived: browser update, cable `flash`, factory image.

**The test is equality, not ordering, and that is a security decision.** This
firmware is open source. Anyone can build an image, install it, and have it write
a payout address of their own into NVS for the official firmware to inherit and
pay out to — so state that was last written by a *different* image is state this
one refuses to act on, whether that image called itself newer or older. An
earlier version of this check compared `<`, and a hostile image only had to stamp
a large number to be waved through as a rollback.

The counter cannot do this on its own, and is not asked to: a stamp in NVS does
not authenticate itself, and an image that gets to run can write `BUILD_ID`'s own
value. What keeps a foreign image off the device is Secure Boot, with Flash
Encryption in RELEASE mode so the key cannot be read back out. This check is the
layer beneath them, and it covers the case that is not an attack at all — an
older release, an engineering build, a factory image, all of which leave settings
behind that the next firmware has no business trusting.

**Every commit is a new `BUILD_ID`.** A rebuild of the same commit — uncommitted
edits included — keeps the id and so keeps the settings; the first build after a
new commit wipes them. To force a wipe without committing, `Factory reset` on the
config page. CI must check out with `fetch-depth: 0`, or every build counts 1.

#### The test

1. Configure the terminal fully — admin code, Wi-Fi, payout address — and take a
   payment, so there is something to lose.
2. Commit (any commit gives a new `BUILD_ID`, and the version on About shows the
   new count and hash), build, and install it (§3.3, or a cable flash).
3. Watch the first boot on the new image.

**Pass — with no cable, on the panel alone:**

- It comes up in first-run setup: it asks for a new admin code. The Wi-Fi tab
  reads *Not configured*, and the Tx tab shows the built-in payout address under
  the red *"this terminal cannot take payments"* line.
- The welcome screen reads **"Updated to 1.0.1. Settings are cleared &mdash; set
  the terminal up again."** &mdash; the second sentence appears *only* when the
  wipe ran.

**Pass — on the serial log:**

```
W (nnn) settings: stamped 1, running build 2 - erasing NVS
```

One boot, not two: the erase happens before the UI task and the Wi-Fi driver
exist, so there is no handle to close first and nothing to restart for.

#### Downgrade, which wipes too

Install the *older* build back over the new one. It wipes again — `stamped 2,
running build 1` — because a lower id is still a different image, and the whole
point is that state from a different image is not trusted. Don't read the second
wipe as a fault; a firmware that came back down is exactly the case the check
exists for.

#### The negative control, which matters as much

Power-cycle the terminal without flashing anything.

**Pass:** no wipe line, the kept line instead, and the terminal comes straight up
on its stored Wi-Fi with the operator's payout address &mdash; not the `config.h`
fallback. Check the Tron recipient in the log against the one you configured; if
it has reverted to the compile-time address, settings were erased when they
should not have been.

```
I (nnn)  settings: build 2 - settings written by this build, kept
I (nnnn) cryptnox_pos: Tron recipient: TWm7PCMn...   <- yours, not config.h's
I (nnnn) cryptnox_pos: Wi-Fi 'Lucky_2.4G': attempt 1/3
I (nnnn) cryptnox_pos: Ready
```

**Fail:** a wipe on every boot is a loop &mdash; the new `BUILD_ID` is not being
written back after the erase. A terminal that re-runs setup after each power cut
is worse than one that never wipes at all.

#### The failure path

If the erase itself fails, nothing is written, so the next boot still sees the
older stored id and tries again:

```
E (nnn) settings: NVS erase failed (ESP_ERR_...) - settings kept
```

The terminal meanwhile keeps working with its old settings. That is the intended
answer: a unit that still takes payments beats a brick, and the panel is not left
insisting the settings were cleared when they were not.

---

## 4. Rollback — the test that decides whether this ships

Everything above assumes new firmware boots. This checks what happens when it
does not. Do it on a bench unit, not a deployed one.

Break a build on purpose — after bring-up, before the image is confirmed:

```c
/* boot.cpp, immediately before ota_mark_valid() — REVERT AFTER TESTING */
abort();
```

```bash
touch CMakeLists.txt
POS_VERSION_TAG=v9.9.9 cmd //c "C:\Cryptnox\cryptnox-pos\scripts\idf-build.bat"   # unmistakable in the log
cp build/cryptnox_pos.bin /tmp/broken.bin
git checkout main/boot.cpp && touch CMakeLists.txt
```

Upload `/tmp/broken.bin`, accept it on the panel, and watch the serial log.

**Pass:**

1. It boots into `9.9.9`, reaches the panel, then panics on the `abort()`.
2. The reset that follows does **not** come back on `9.9.9` — the bootloader
   reports falling back to the other app and the terminal boots the previous
   version.
3. About shows the old version; `/api/state` shows the old `slot`.
4. It takes a payment.

**Fail:** a terminal that boot-loops on `9.9.9` means rollback is not compiled in
(§0) or `ota_mark_valid()` is being called too early. Both make a bad build
unrecoverable without opening the case — which is the entire failure this
mechanism exists to prevent.

Worth doing the harsher variant once: move the `abort()` to *before* `ui_init()`,
so the image dies with a blank screen. The outcome must be identical. A terminal
that shows nothing and recovers by itself is the whole point.

---

## 5. Signed builds

Everything above runs on an unsigned dev build, where any correctly-formatted
image is accepted. The release path must be tested separately, on a sacrificial
unit, because it is the only thing that makes `POST /api/ota` safe to expose:

```bash
idf.py secure-generate-signing-key --version 2 secure_keys/secure_boot_signing_key.pem
idf.py -D "SDKCONFIG_DEFAULTS=sdkconfig.defaults;sdkconfig.defaults.flash_encryption;sdkconfig.defaults.release" build
```

| Check | Expected |
|---|---|
| Upload an image signed with the same key | installs normally |
| Upload the *unsigned* dev build to the signed unit | `400`, `image rejected: ESP_ERR_OTA_VALIDATE_FAILED` |
| Upload an image signed with a **different** key | same rejection |
| Flip one byte in the middle of a signed image (`dd`) | same rejection |

The third row is the one that matters. Generate a throwaway second key, sign a
build with it, and confirm the terminal refuses it — that proves the check is
verifying *the* key and not merely the presence of a signature.

Note the release overlay also sets `CONFIG_ESP32_REV_MIN_3`: on pre-ECO3 silicon
the image will not boot at all. Check `esptool.py chip_id` first.

---

## 6. Regressions on the money path

The update window is reachable from the settings menu, which is new — the setup
portal never was. These must pass on a terminal that is **not** being updated:

| Check | Expected |
|---|---|
| Boot an untouched terminal | `Ready`, no `ota` lines beyond the version, no new warnings |
| Open Update, tap Done, take a payment | unaffected |
| Open Update, upload nothing, wait out the window, take a payment | unaffected |
| **Upload while a payment is in progress** | see below |
| Factory reset after an update | settings gone, firmware version unchanged — a reset is not a downgrade |
| About tab layout | version, the Update row, then the licence text, all reachable by scrolling |

### 6.1 Upload during a payment

Start a payment and leave it on **Place card**, then upload a valid image.

**Pass:** the upload completes and is verified, but the panel offer **does not
appear over the transaction**. It appears once the payment finishes or is
cancelled. `UI_EVENT_OTA_STAGED` goes through the main task's queue, which a
payment occupies, so the offer waits its turn.

**Fail:** an install card appearing over a customer's transaction, or an
`esp_restart()` between signing and broadcast. Repeat this one with the card
actually tapped, mid-signing, before shipping.

---

## 7. What this plan does not cover

- **Flash encryption + OTA together.** `esp_ota_write()` encrypts transparently,
  so it should work, but nothing here proves it. Run §3 and §4 on an
  encryption-enabled unit before shipping one.
- **Two browsers uploading at once.** `s_receiving` refuses the second with
  `409`; the interleaving of two sockets into one `httpd` task is untested.
- **Heap headroom during an upload.** LVGL, `httpd` and the 4 kB OTA buffer
  coexist on an ESP32 with no measurement of free heap at the worst moment.
- **A hostile image that is validly signed.** Out of scope by construction: the
  signature is the trust boundary, so anything past it is trusted.
- **Resumed uploads.** There are none — a dropped connection means starting over.

<!-- ponytail: §1.1 and the page-extraction cross-check are manual. Wire them
     into CI when CI exists to wire them into. -->

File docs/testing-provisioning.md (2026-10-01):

# Testing the config portal

Test plan for `main/provision.cpp` — the SoftAP + captive portal, in both its
wizard and admin modes. Design notes are in
[config-portal.md](config-portal.md).

Four layers, cheapest first. Do them in order — a failure at layer 1 makes the
rest meaningless.

1. **Host** — the urlencoded parser and the address checks, no hardware.
2. **Bench, wizard** — a laptop joined to the setup AP, `curl` and `nslookup`.
   Proves the DNS and HTTP halves independently of any phone's opinion.
3. **Bench, admin** — a laptop joined to the same setup AP, admin mode.
4. **Handset** — real iOS and real Android. The only thing that proves the portal
   *opens by itself*, which is the whole feature.

---

## 0. Prerequisites

The CYD's CH340 moves COM ports between sessions. Find it first:

```bash
powershell -NoProfile -Command "[System.IO.Ports.SerialPort]::GetPortNames()"
```

Build, flash and read the log (substitute your port). Run the `.bat` directly —
`cmd //c` works only in Git Bash, and in PowerShell or cmd it opens a nested shell
and runs nothing at all, silently:

```bash
./scripts/idf-build-flash.bat COM7        # Git Bash
./scripts/idf-monitor.bat COM7 20
```

```powershell
& .\scripts\idf-build-flash.bat COM7      # PowerShell
& .\scripts\idf-monitor.bat COM7 20
```

The port defaults to COM3 in both scripts. `idf-monitor.bat` wraps
`serial_tail.py` because `idf.py monitor` needs a tty.

### Getting into first-run setup

The wizard runs on a terminal that is not configured, and there are two ways to be
unconfigured:

* **no admin code** (`!settings_has_admin_code()`) — a virgin or factory-reset
  unit. Welcome screen, admin code on the panel, then the browser flow.
* **no payout address** (neither `settings_has_payout(false)` nor `(true)`) — a
  half-configured unit, which is what a firmware update leaves behind if setup was
  never finished: NVS survives the update, so the admin code is still there. No
  welcome and no new code — it opens straight on the QR code and asks for the code
  the unit already has. If a network is already saved the wizard ends at the
  addresses rather than asking for a venue passphrase it already knows, so the path
  is `2 → 3 → 4 → 6`.

Two ways to get back to the first of those:

| Method | What it costs | When |
|---|---|---|
| Settings → About → Reset → confirm | admin code, Wi-Fi creds, brightness, fees, payout addresses, contracts, **and** the TLS identity in the `prov` namespace | normal test loop |
| `idf.py -p COM7 erase-flash` then flash | all of the above | testing a truly virgin unit |

Both clear the `prov` namespace, so both exercise TLS-key generation. The AP
passphrase is not stored at all — every portal open shows a different one, so check
the panel against the log each time rather than reusing yesterday's photo. Watch for
this once per wipe:

```
W (nnnn) prov: generating this terminal's TLS identity (once)
```

### The shortened wizard

To reach the `1 → 2 → 3 → 5 → 6` path (already configured, network gone): finish
setup, then take the venue AP down (or change its passphrase) and reboot. The
terminal should raise the setup AP and skip the address step.

---

## 1. Host tests

```bash
bash scripts/checks.sh          # everything below, in one command
```

Individually, if one of them fails and you want it on its own:

```bash
for t in test_eth_addr test_hardening test_tron_tx test_prov_form \
         test_addr_check test_json_out test_ota_version; do
  g++ -std=c++14 -Wall -Imain -Icryptnox-sdk-esp32/cryptnox-sdk-cpp \
      tests/units/$t.cpp -o $t && ./$t || exit 1
done
```

* `test_prov_form` covers `main/form_parse.h`: prefix anchoring (`wifipass` must
  not answer a lookup for `pass`), percent and plus decoding, malformed escapes,
  encoded `&` and `=` inside values, truncation at the buffer boundary.
* `test_addr_check` covers `main/addr_check.h`: the structural Tron check, and in
  particular that an empty string is **not** base58.
* `test_json_out` covers `main/json_out.h`: an SSID with a quote, a backslash, a
  trailing backslash or a control byte in it, and truncation at every buffer size
  from 1 to 40 — the output has to stay parseable JSON at all of them, because a
  response the page cannot parse is a blank config UI during setup.
* `test_eth_addr` now also covers `eth_addr_format` — the EIP-55 round trip that a
  card-derived payout address goes through.

All must print `OK`.

Then the page itself, which the C compiler cannot check:

```bash
python tools/check_portal_page.py --emit-js build/portal_page.js
node tools/test_portal_render.js build/portal_page.js
```

**Pass:** `portal page OK (… bytes, … ids, all wired)` then `portal render test OK`.
The first extracts the two string literals from `provision.cpp`, runs the
`<script>` body through `node --check`, and asserts every element id is referenced
from both sides. The second drives `render()` against each `(mode, step, authed,
pending)` the device can report and asserts which sections are visible — the wizard
showing two steps at once, or the admin page growing a Continue button, fails here.

Run both before flashing, not after: a typo in that page is a wizard nobody can
complete, on a device with no console to read the reason from.

---
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

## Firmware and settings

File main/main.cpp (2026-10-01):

/*
 * SPDX-License-Identifier: LGPL-3.0-or-later
 * Copyright (c) 2026 Cryptnox SA
 */

/**
 * @file main.cpp
 * @ingroup app
 * @brief cryptnox-pos entry point: touchscreen USDC payment terminal.
 *
 * Drives the amount → confirm → sign → broadcast flow on the Cheap Yellow
 * Display, signing EIP-1559 USDC transfers on a Cryptnox card via PN532.
 */


#include "pos_app.h"

/* The main loop wakes at least this often with nothing to do, so it can feed the
 * task watchdog (CONFIG_ESP_TASK_WDT_TIMEOUT_S is 60). */
#define MAIN_LOOP_TICK_MS    5000U
#define HEAP_LOG_PERIOD_US   (10LL * 60LL * 1000000LL)

QueueHandle_t s_ui_queue = NULL;

/* Set by the UI task on Cancel during PLACE_CARD; the main task checks it after
 * signing to skip the FAILED flash. Atomic because it crosses tasks. */
std::atomic<bool> s_user_cancelled{false};

/**
 * @brief UI-task callback: forward a touch event to the main task queue.
 *
 * Runs in the UI task context.  A Cancel tap also raises the atomic
 * @ref s_user_cancelled flag so the in-flight signing flow can abort
 * without waiting for the queue to drain.
 *
 * @param[in] event   UI event identifier.
 * @param[in] payload Event payload (amount in USDC base units, or 0).
 */
void ui_event_dispatch(ui_event_t event, uint64_t payload) {
    if (event == UI_EVENT_CONFIRM_CANCEL) {
        s_user_cancelled = true;
    }
    ui_msg_t msg = { event, payload };
    (void)xQueueSend(s_ui_queue, &msg, 0);
}

/**
 * @brief ESP-IDF application entry point: bring-up, then the main interaction
 *        loop (amount → confirm → sign+broadcast).
 */
extern "C" void app_main(void)
{
    const pos_hw_t hw = pos_boot();
    CryptnoxWallet    &wallet         = hw.wallet;
    Pn532NfcTransport &nfcTransport   = hw.transport;
    CW_CryptoProvider &cryptoProvider = hw.crypto;

    /* ── Main interaction loop ────────────────────────────────── */
    /* A sale that was between broadcast and verdict when the terminal went down
     * (brownout, panic, somebody pulling the plug) is picked up where it stopped:
     * same hash, same checks, and the verdict on the panel — Unconfirmed with
     * "Check again" if the network is not back yet. */
    if (settings_inflight_load(&s_inflight, sizeof(s_inflight)) && s_inflight.active) {
        ESP_LOGW(TAG, "resuming the sale in flight at reset: %s", s_inflight.hash);
        settle_inflight();
    } else {
        settings_inflight_clear();
        ui_show_amount_entry();
    }

    pos_amount_t pending_amount;
    pos_amount_set(&pending_amount, 0U);
    ui_msg_t msg;

    /* A card read from the admin page yields both addresses, but the panel shows
     * one proposal at a time: the Tron one waits here until the Ethereum one is
     * resolved, and the restart that applies a stored address waits for both. */
    char card_tron[SETTINGS_PAYOUT_MAX] = "";
    bool restart_due = false;

    /* On the task watchdog from here on: a loop that stops coming back to its
     * queue is a hung terminal, and resetting it beats a frozen panel. Boot above
     * is not subscribed — the wizard and the picker wait on people. */
    if (esp_task_wdt_add(NULL) != ESP_OK) {
        ESP_LOGE(TAG, "main loop not on the task watchdog");
    }
    int64_t next_heap_log_us = esp_timer_get_time() + HEAP_LOG_PERIOD_US;

    while (true) {
        wdt_feed();
        /* Heap fragmentation is the likely way TLS handshakes start failing after
         * days (fresh handshake per call, no PSRAM); log it every ten minutes. */
        if (esp_timer_get_time() >= next_heap_log_us) {
            next_heap_log_us = esp_timer_get_time() + HEAP_LOG_PERIOD_US;
            ESP_LOGI(TAG, "heap: %u free, %u largest block",
                     static_cast<unsigned>(esp_get_free_heap_size()),
                     static_cast<unsigned>(
                         heap_caps_get_largest_free_block(MALLOC_CAP_DEFAULT)));
        }
        if (xQueueReceive(s_ui_queue, &msg, pdMS_TO_TICKS(MAIN_LOOP_TICK_MS)) != pdTRUE) {
            continue;
        }

        switch (msg.event) {
            case UI_EVENT_AMOUNT_CONFIRMED: {
                pos_amount_set(&pending_amount, msg.payload);
                /* Refuse before the customer taps: offline, every request the sale
                 * makes would fail after the card and PIN; without a clock TLS
                 * cannot validate a certificate. */
                if (!net_wifi_online() || (wall_ms() == 0U)) {
                    ui_show_tx_status(UI_TX_STATE_FAILED,
                                      !net_wifi_online()
                                          ? "Offline - re-joining the Wi-Fi"
                                          : "Waiting for network time");
                    pos_amount_set(&pending_amount, 0U);
                    break;
                }
                /* Refuse rather than fall back. settings_get_payout() answers with
                 * the config.h recipient when nobody set one, which would send a
                 * customer's money to an address the operator never chose while
                 * looking entirely normal. A till never told where the money goes
                 * declines the sale, as it does for an unset token contract. */
                if (!settings_has_payout(chain_is_tron())) {
                    ui_show_tx_status(UI_TX_STATE_FAILED,
                                      "Payout address not configured");
                    pos_amount_set(&pending_amount, 0U);
                    break;
                }
                /* Set, but it failed the checksum at boot: the dual store holds
                 * the config.h fallback, which nobody chose for this till. */
                if (s_payout_bad[chain_is_tron() ? 1 : 0]) {
                    ui_show_tx_status(UI_TX_STATE_FAILED,
                                      "Payout address invalid - set it again");
                    pos_amount_set(&pending_amount, 0U);
                    break;
                }
                const token_t *tok = active_token();
                /* Say so here rather than after the customer has tapped a card:
                 * a placeholder contract means this asset was never set up. */
                if ((tok != NULL) && !tok->ok) {
                    ui_show_tx_status(UI_TX_STATE_FAILED,
                                      "Token contract not configured");
                    pos_amount_set(&pending_amount, 0U);
                    break;
                }
                char dec_err[64];
                if (!token_decimals_ok(settings_get_chain(), dec_err,
                                       sizeof(dec_err))) {
                    ui_show_tx_status(UI_TX_STATE_FAILED, dec_err);
                    pos_amount_set(&pending_amount, 0U);
                    break;
                }
                /* Reconcile amount + recipient (+ token contract) before they
                 * are shown to the customer — displayed value must equal what
                 * gets signed. */
                if (!IS_TRUE32(amount_consistent(&pending_amount)) ||
                    !IS_TRUE32(address_consistent(active_dest())) ||
                    ((tok != NULL) &&
                     !IS_TRUE32(address_consistent(&tok->addr)))) {
                    pos_handle_anomaly("pre-display reconcile");
                    ui_show_tx_status(UI_TX_STATE_FAILED, "Integrity check failed");
                    pos_amount_set(&pending_amount, 0U);
                    break;
                }
                /* No balance check here: the payer is the card, and nobody has
                 * tapped yet. evm_balance_ok / tron_balance_ok run once it is
                 * present. */
                ui_refresh_addresses();
                /* Show the resolved recipient, NOT the config.h literal: they
                 * differ on a terminal provisioned through the setup page, and the
                 * operator checks the address against this row. s_payout_* is the
                 * string s_dest / s_tron_dest were parsed from, so what is
                 * displayed is what gets signed. */
                evm_fees_wei(chain_is_polygon(), &s_sale_fee.max_fee,
                             &s_sale_fee.prio_fee);
                char fee_txt[40];
                sale_fee_text(fee_txt, sizeof(fee_txt));
                ui_show_confirm(pending_amount.amount_minor,
                                chain_is_tron() ? s_payout_tron : s_payout_eth,
                                fee_txt);
                break;
            }

            case UI_EVENT_CONFIRM_CANCEL:
                ui_show_amount_entry();
                break;

            case UI_EVENT_PIN_ENTERED: {
                if (pending_amount.amount_minor == 0U) {
                    /* No fresh AMOUNT_CONFIRMED preceded this — likely a stale
                     * event from a stuck touch or queue replay. Drop it. */
                    ESP_LOGW(TAG, "stale PIN_ENTERED ignored");
                    break;
                }
                /* Fetch the keypad PIN (UI wipes its own copy on read). */
                char   pin[16]   = { 0 };
                size_t pin_chars = ui_take_pin(pin, sizeof(pin));

                s_user_cancelled = false;
                char err_msg[64] = { 0 };
                inflight_t *fl = &s_inflight;
                CW_Utils::secure_wipe(reinterpret_cast<uint8_t *>(fl), sizeof(*fl));
                /* The decided amount, for the final gate — in the record before
                 * the sign, because the record is persisted before the broadcast
                 * (inflight_persist) and a resumed poll needs it too. */
                fl->decided = pending_amount;
                const bcast_t sent =
                    pay_sign_and_broadcast(wallet, nfcTransport, cryptoProvider,
                                           &pending_amount, pin, pin_chars, fl,
                                           err_msg, sizeof(err_msg));
                /* scrub our copy of the PIN as soon as signing is done. */
                CW_Utils::secure_wipe(reinterpret_cast<uint8_t *>(pin), sizeof(pin));

                /* Clear pending so the next sign needs a fresh New Payment flow. */
                pos_amount_set(&pending_amount, 0U);
                if (sent != BCAST_FAILED) {
                    /* Out of our hands now, whatever the cancel flag says: a
                     * signed transaction the node may hold is settled by the
                     * chain, not by a tap on the panel. */
                    fl->active          = true;
                    fl->broadcast_known = (sent == BCAST_SENT);
                    settle_inflight();
                } else if (!s_user_cancelled) {
                    settings_inflight_clear();   /* refused: nothing went out */
                    ui_show_tx_status(UI_TX_STATE_FAILED, err_msg);
                } else {
                    /* Cancelled — before the broadcast, so nothing went out
                     * either; drop any record so a reboot does not resume it. */
                    settings_inflight_clear();
                    /* Cancel during PLACE_CARD — UI already on amount entry. */
                }
                break;
            }

            case UI_EVENT_TX_RECHECK:
                /* "Check again" on the Unconfirmed screen: same sale, same hash. */
                if (s_inflight.active) {
                    settle_inflight();
                } else {
                    ui_show_amount_entry();
                }
                break;

            case UI_EVENT_TX_RETRY:
                /* New sale — or, from Unconfirmed, the operator's explicit
                 * "I have checked" Clear. The record goes either way: the nonce
                 * is read from "latest", so if the old one is still pending a
                 * new sale replaces it rather than landing beside it. */
                s_inflight.active = false;
                settings_inflight_clear();
                ui_show_amount_entry();
                break;

            case UI_EVENT_PROV_STOP:
                /* Run here, not on the UI task: prov_stop() blocks for up to ~2 s
                 * and would freeze the panel. */
                if (prov_mode() != PROV_MODE_OFF) { prov_stop(); }
                break;

            case UI_EVENT_OTA_STAGED:
                /* Uploaded and verified firmware; nothing boots until it is
                 * accepted on the panel. Routed through this queue so the offer
                 * waits behind a payment rather than appearing over one. */
                ui_show_ota_confirm();
                break;

            /* ── The admin page, open beside a running terminal ──
             * Same handlers as the wizard's, and for the same reason: a browser may
             * propose, only the panel may accept. Routed through this queue so an
             * offer waits behind a payment in progress rather than appearing over
             * a customer's transaction. */
            case UI_EVENT_PROV_AUTH:
                ui_show_prov_auth();
                break;

            case UI_EVENT_PROV_VALUE:
                ui_show_prov_confirm();   /* decimals: see token_decimals_ok */
                break;

            case UI_EVENT_PROV_VALUE_SET:
            case UI_EVENT_PROV_VALUE_NO:
                if (msg.event == UI_EVENT_PROV_VALUE_SET) { restart_due = true; }
                /* The panel slot is free again: offer the parked Tron address. */
                if (card_tron[0] != '\0') {
                    (void)prov_propose(PROV_ASK_PAYOUT_TRON, card_tron);
                    card_tron[0] = '\0';
                    break;
                }
                if (!restart_due) { break; }
                /* Stored. The recipient and contract dual stores are built at boot
                 * from validated strings, so the change applies through a restart
                 * rather than a second, re-validating path into the money code. */
                ESP_LOGW(TAG, "config changed from the admin page - restarting");
                prov_stop();
                ui_set_boot_status("Applying settings");
                vTaskDelay(pdMS_TO_TICKS(600));
                esp_restart();
                break;

            case UI_EVENT_PROV_CARD: {
                /* Same flow as the wizard: PIN on the keypad, tap, then the
                 * accept-on-the-panel handshake. */
                s_user_cancelled = false;
                prov_set_note("Follow the terminal screen.");
                ui_show_card_pin();
                break;
            }

            case UI_EVENT_CARD_PIN: {
                char   pin[16]   = { 0 };
                size_t pin_chars = ui_take_pin(pin, sizeof(pin));
                char   c_eth[SETTINGS_PAYOUT_MAX]  = "";
                char   c_tron[SETTINGS_PAYOUT_MAX] = "";
                char   err[48] = { 0 };
                const bool got = card_read_payouts(wallet, nfcTransport,
                                                   cryptoProvider,
                                                   pin, pin_chars,
                                                   c_eth, sizeof(c_eth),
                                                   c_tron, sizeof(c_tron),
                                                   err, sizeof(err));
                CW_Utils::secure_wipe(reinterpret_cast<uint8_t *>(pin), sizeof(pin));
                if (!got) {
                    /* No setup screen mid-shift: show the reason on the failure
                     * screen rather than dropping silently back to the keypad. */
                    prov_set_note(err);
                    ui_show_tx_status(UI_TX_STATE_FAILED, err);
                    break;
                }
                ui_show_amount_entry();
                prov_set_note("Accept each address on the terminal screen.");
                /* Ethereum first if there is one; Tron waits in card_tron and is
                 * offered when that proposal is resolved (see PROV_VALUE_SET). */
                card_tron[0] = '\0';
                if (c_eth[0] != '\0') {
                    (void)prov_propose(PROV_ASK_PAYOUT_ETH, c_eth);
                    (void)snprintf(card_tron, sizeof(card_tron), "%s", c_tron);
                } else if (c_tron[0] != '\0') {
                    (void)prov_propose(PROV_ASK_PAYOUT_TRON, c_tron);
                }
                break;
            }

            case UI_EVENT_PROV_SCAN: {
                net_wifi_ap_t aps[16];
                const uint16_t n_aps = net_wifi_scan(aps, 16);
                prov_set_scan(aps, n_aps);
                break;
            }

            case UI_EVENT_WIFI_SCAN: {
                /* Scan runs in this task so the UI stays responsive. */
                net_wifi_ap_t aps[16];
                uint16_t n = net_wifi_scan(aps, 16);
                /* Opened from settings, not after a failure — no note. */
                ui_show_wifi_list(aps, n, NULL);
                break;
            }

            case UI_EVENT_WIFI_TRY: {
                char w_ssid[33] = { 0 };
                char w_pass[65] = { 0 };
                if (ui_take_wifi_creds(w_ssid, sizeof(w_ssid),
                                       w_pass, sizeof(w_pass)) > 0U) {
                    ui_show_wifi_connecting(w_ssid);

                    /* Same rule as boot: associating proves nothing, so a clock
                     * sync must prove the uplink before saved credentials are
                     * overwritten. One round only; the operator can tap again. */
                    const char *why = NULL;
                    if (!net_wifi_connect(w_ssid, w_pass)) {
                        why = NOTE_JOIN_FAILED;
                    } else if (!net_time_sync(15000U)) {
                        ESP_LOGW(TAG, "'%s' joined but has no network time -"
                                      " not saved", w_ssid);
                        why = NOTE_NO_TIME;
                    } else {
                        settings_set_wifi(w_ssid, w_pass);   /* persist for next boot */
                        /* From the config page: the terminal must never be on a
                         * network *and* serving that page (httpd binds every
                         * interface), so close it rather than hand the forms to
                         * the new LAN. */
                        if (prov_mode() != PROV_MODE_OFF) { prov_stop(); }
                        ui_show_amount_entry();
                    }

                    if (why != NULL) {
                        /* The radio is still on the rejected network, so the
                         * terminal would look ready while every payment fails.
                         * Roll back to the saved network boot already proved. */
                        char b_ssid[33] = { 0 };
                        char b_pass[65] = { 0 };
                        if (settings_get_wifi(b_ssid, sizeof(b_ssid),
                                              b_pass, sizeof(b_pass)) &&
                            (b_ssid[0] != '\0')) {
                            ESP_LOGW(TAG, "rolling back to saved network '%s'",
                                     b_ssid);
                            ui_show_wifi_connecting(b_ssid);
                            if (!net_wifi_connect(b_ssid, b_pass) &&
                                (prov_mode() == PROV_MODE_OFF)) {
                                /* The saved network is down too; keep retrying
                                 * it in the background. */
                                net_wifi_keep_trying();
                            }
                        }
                        CW_Utils::secure_wipe(
                            reinterpret_cast<uint8_t *>(b_pass), sizeof(b_pass));

                        /* prov_stop() re-joins with the restored credentials, but
                         * no association may stay up while the config page is
                         * served: drop it, back to AP-only. */
                        if (prov_mode() != PROV_MODE_OFF) { net_wifi_disconnect(); }

                        /* Back to the picker with the reason, so another network
                         * can be chosen instead of a dead end. */
                        net_wifi_ap_t aps[16];
                        uint16_t n = net_wifi_scan(aps, 16);
                        ui_show_wifi_list(aps, n, why);
                    }
                }
                CW_Utils::secure_wipe(reinterpret_cast<uint8_t *>(w_pass), sizeof(w_pass));
                break;
            }

            default:
                break;
        }
    }
}

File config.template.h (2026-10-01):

/*
 * SPDX-License-Identifier: LGPL-3.0-or-later
 * Copyright (c) 2026 Cryptnox SA
 */

/**
 * @file config.template.h
 * @brief Build-time configuration template — copy to main/config.h and fill
 *        in (main/config.h is gitignored, NEVER commit it).
 */

#ifndef CONFIG_H
#define CONFIG_H

#include <stdint.h>

/* =========================
 * WiFi
 * ========================= */
/* Wi-Fi is NOT set here. It is chosen on the device during setup — from a browser,
 * out of a list the terminal scans for itself — and stored in NVS. No SSID or
 * password is baked into the firmware. See docs/config-portal.md. */

/* =========================
 * Ethereum / RPC
 * ========================= */
/**
 * Choose ONE provider below and comment out the other.
 *
 * Option A — PublicNode (free, no account required)
 *   Keep the lines under "Option A" as-is.
 *
 * Option B — Infura (requires a free account at app.infura.io)
 *   1. Create an API key in the Infura dashboard.
 *   2. In the key's Settings tab, reveal (or generate) the API Secret.
 *   3. Comment out Option A, uncomment the lines under "Option B" and
 *      fill in the values (the API Secret must have NO leading or
 *      trailing spaces).
 */

/* Not here: the panel clock's UTC offset. It is an operator setting, picked
 * from a list on the config page under "Clock" and stored in NVS — a fixed
 * offset rather than a timezone, because the DST rules that would make it
 * automatic cost 64 KB of the app slot (measured) and moving it twice a year
 * from a browser does not. */

/* --- Option A: PublicNode ----------------------------------------- */
#define RPC_HOST       "ethereum-sepolia-rpc.publicnode.com"
#define RPC_URL        "https://" RPC_HOST
/* No authentication needed — leave RPC_PROJECT_ID / RPC_API_SECRET
 * undefined (or commented out) when using PublicNode.               */

/* --- Option B: Infura --------------------------------------------- */
/* #define RPC_HOST        "sepolia.infura.io"                        */
/* #define RPC_PORT        443                                        */
/* #define RPC_PROJECT_ID  "<YOUR_INFURA_PROJECT_ID>"                 */
/* #define RPC_URL         "https://sepolia.infura.io/v3/" RPC_PROJECT_ID */
/* #define RPC_API_SECRET  "<YOUR_INFURA_API_SECRET>"                 */

/* --- Optional: pin the RPC TLS certificate ----------- */
/* By default the HTTPS chain is validated against the full Mozilla CA bundle
 * (~150 CAs, any of which could MITM). Define RPC_CA_CERT_PEM with the
 * endpoint's certificate (leaf, or — more stable across renewals — its issuing
 * CA) to trust ONLY that. Fetch it with:
 *   openssl s_client -connect ethereum-sepolia-rpc.publicnode.com:443 -showcerts </dev/null
 * then paste the relevant PEM block as a C string literal, e.g.:
 *   #define RPC_CA_CERT_PEM "-----BEGIN CERTIFICATE-----\n" \
 *                           "MIIB...\n" \
 *                           "-----END CERTIFICATE-----\n"
 * Note: pinning ties the build to that endpoint — update it if you change RPC.
 * It is applied on the production endpoint (RPC_URL_MAIN) too, so a pin has to
 * cover whichever network the terminal is switched to, or the mainnet side fails
 * TLS with nothing on screen to say why. */

/* The card PIN is NOT set here — the operator types it on the touchscreen
 * keypad at sign time, and it is scrubbed from RAM right after signing.
 * Nothing PIN-related is baked into the firmware. */

/* =========================
 * Ethereum Addresses
 * ========================= */
/* Sender address — the card's m/44'/60'/0'/0/0 key, lowercase hex, no 0x */
#define ADDR_FROM         "<SENDER_ADDRESS>"

/* FALLBACK recipient address — where transfers go until an operator sets one on
 * the device (no 0x). Setup asks for the real one and stores it in NVS, either
 * typed in a browser or read off the operator's Cryptnox card; this value is what
 * a terminal pays to before that happens, so it is worth being a real address of
 * yours rather than a placeholder.
 *
 * MUST be in EIP-55 mixed-case checksum form: the firmware verifies the checksum
 * at boot and refuses to start on a mismatch, catching the most probable typo of
 * the recipient. An all-lowercase address is accepted but bypasses that typo
 * protection (and logs a warning at boot).
 *
 * Note that an asset whose payout address was never *stored* is not offered on the
 * amount screen at all — the fallback keeps a configured terminal working, it does
 * not make an unconfigured one sell things. See docs/config-portal.md. */
#define ADDR_TO           "<RECIPIENT_ADDRESS_EIP55>"

/* FALLBACK USDC ERC-20 contract address (Sepolia testnet, no 0x). Also settable
 * from the config page, with the same dual-store and on-screen accept as the
 * recipient — the contract decides which asset moves.
 * Same rule as ADDR_TO — use the EIP-55 mixed-case form for boot-time
 * checksum verification. */
#define ADDR_USDC         "<USDC_CONTRACT_ADDRESS_EIP55>"
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

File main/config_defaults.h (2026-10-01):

/*
 * SPDX-License-Identifier: LGPL-3.0-or-later
 * Copyright (c) 2026 Cryptnox SA
 */

/**
 * @file config_defaults.h
 * @brief config.h, plus a default for every key added after the first config.h
 *        files shipped — so an older config.h still builds.
 */

#ifndef CONFIG_DEFAULTS_H
#define CONFIG_DEFAULTS_H

#include "config.h"

/* Tron TRC-20 support post-dates the first config.h files in the field. An
 * empty contract fails its base58 decode at boot, which disables that asset
 * rather than breaking the build of a config that predates it. */
#ifndef TRON_ADDR_USDT
#define TRON_ADDR_USDT  ""
#endif
/* Same story for every asset added since: an empty contract fails its parse at
 * boot and only that one asset is refused, so a config.h written before it
 * existed still builds and still charges in whatever it was set up for. */
#ifndef TRON_ADDR_USDC
#define TRON_ADDR_USDC  ""
#endif
#ifndef ADDR_USDT
#define ADDR_USDT  ""
#endif
#ifndef POLY_ADDR_USDC
#define POLY_ADDR_USDC  ""
#endif
#ifndef POLY_ADDR_USDT
#define POLY_ADDR_USDT  ""
#endif
/* Polygon needs an endpoint and a chain id of its own. A config.h that predates
 * Polygon support falls back to the Ethereum ones, which is harmless: its assets
 * have no contract either, so they are refused before anything is signed. */
#ifndef POLY_RPC_URL
#define POLY_RPC_URL  RPC_URL
#endif
#ifndef CHAIN_ID_AMOY
#define CHAIN_ID_AMOY  CHAIN_ID_SEPOLIA
#endif
#ifndef POLY_MIN_PRIORITY_FEE_GWEI
#define POLY_MIN_PRIORITY_FEE_GWEI  30U
#endif
/* A plain value transfer to an account costs exactly 21000 gas — no contract
 * runs — so GAS_LIMIT_ERC20's allowance for a token's storage writes is not
 * merely generous here, it is the wrong number. */
#ifndef GAS_LIMIT_NATIVE
#define GAS_LIMIT_NATIVE  21000ULL
#endif
#ifndef TRON_TRC20_FEE_LIMIT_SUN
#define TRON_TRC20_FEE_LIMIT_SUN  100000000ULL
#endif
/* The production networks. A config.h written before they were selectable falls
 * back to its testnet values everywhere, so such a build keeps working exactly as
 * it did — the switch on the config page then moves nothing, which is the right
 * answer for a file that names no mainnet to move to. The empty contracts are the
 * usual "this asset was never set up": refused, with the rest still working. */
#ifndef RPC_URL_MAIN
#define RPC_URL_MAIN  RPC_URL
#endif
#ifndef POLY_RPC_URL_MAIN
#define POLY_RPC_URL_MAIN  POLY_RPC_URL
#endif
#ifndef TRON_URL_MAIN
#define TRON_URL_MAIN  TRON_URL
#endif
#ifndef CHAIN_ID_MAINNET
#define CHAIN_ID_MAINNET  CHAIN_ID_SEPOLIA
#endif
#ifndef CHAIN_ID_POLYGON
#define CHAIN_ID_POLYGON  CHAIN_ID_AMOY
#endif
#ifndef ADDR_USDC_MAIN
#define ADDR_USDC_MAIN  ""
#endif
#ifndef ADDR_USDT_MAIN
#define ADDR_USDT_MAIN  ""
#endif
#ifndef POLY_ADDR_USDC_MAIN
#define POLY_ADDR_USDC_MAIN  ""
#endif
#ifndef POLY_ADDR_USDT_MAIN
#define POLY_ADDR_USDT_MAIN  ""
#endif
#ifndef TRON_ADDR_USDT_MAIN
#define TRON_ADDR_USDT_MAIN  ""
#endif
#ifndef TRON_ADDR_USDC_MAIN
#define TRON_ADDR_USDC_MAIN  ""
#endif

#endif /* CONFIG_DEFAULTS_H */

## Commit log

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2026-05-26 Remove legacy flash_pkg/flash.bat
    The standalone batch script is replaced by auto_flash.ps1 at the repo
    root, which sources the ESP-IDF v5.5 environment and runs the
    build/flash/monitor chain end-to-end.
2026-05-26 Add UI: TFT_eSPI + XPT2046_Touchscreen with USDC payment flow
    Switch the UI stack from LVGL/esp_lcd to TFT_eSPI + XPT2046_Touchscreen
    (both vendored under components/) for known-good Cheap Yellow Display
    support. Arduino-as-component provides the Arduino runtime; everything
    else (PN532, Cryptnox SDK, eth_rpc, WiFi) stays on native IDF.
    UI flow:
    Splash -> Amount entry (+/-1 USDC, +/-0.01 USDC, Confirm)
    -> Confirm (amount + destination, Cancel/Send)
    -> Tx status (Place card / Signing / Broadcasting / Sent / Failed)
    Anti-double-trigger: pending_amount resets after each sign and the UI
    queue is drained, so a stuck touch or queue replay cannot auto-fire a
    second transaction. C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
    [partitions.csv]
2026-05-26 Make Cancel responsive and prevent stuck-touch screen cascades
    UI: tap detection now requires a "finger up" moment between taps so a
    held touch or rapid press doesn't chain Cancel -> CONFIRM -> Send when
    those buttons sit at the same y. Tap on Send instantly switches to the
    Transaction screen with "Preparing..." so the user doesn't wait on the
    RPC nonce call before seeing feedback.
    main: replace wallet.connect() with a manual loop that polls
    inListPassiveTarget + establishSecureChannel and checks s_user_cancelled
    between PN532 attempts. After Cancel, sign_and_broadcast aborts within
    one PN532 timeout (~5 s) instead of the full retry budget (~26 s), so a
    subsequent Amount -> Confirm flow is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
    [main.cpp]
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2026-05-27 Bump cryptnox-sdk-esp32 to feature/esp32-cyd (228edd0)
    Pin the submodule on the new feature/esp32-cyd branch tip, which carries
    the I²C PN532 transport built on top of upstream main (security fixes,
    ext-frame support, CW_Curve API, platform abstraction). Update
    .gitmodules to track the renamed branch.
    main.cpp: the new CryptnoxWallet constructor requires a CW_Platform&;
    instantiate the SDK-provided ESP32Platform and pass it through. Add
    esp32_platform to main/CMakeLists.txt REQUIRES.
    ui.cpp: drop the dead format_amount helper (replaced by inlined
    snprintf in draw_amount_centered) — was breaking -Werror=unused-function.
    README.md: ESP32-2432S028R -> ESP32-2432S028 (drop the variant suff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
    [main.cpp]
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2026-06-03 doxygen workflow: fetch Doxygen with curl --fail instead of wget -q
    wget -q silently returned exit 8 on the GitHub Actions Azure runner
    even though the URL probes 200 OK from elsewhere. Switch to curl
    -fsSL which surfaces HTTP errors with a readable message, and add
    set -ex so each step is visible on failure.
2026-06-03 Fix cppcheck style findings: C-style casts and dead ternary
    eth_rpc.cpp: replace (char *) casts with reinterpret_cast on the
    WiFi SSID/password buffers and static_cast on malloc returns. Mark
    the strchr result pointer const where it's only read.
    keccak256.cpp: replace (uint8_t *)state with reinterpret_cast.
    ui.cpp: collapse the dead 'half = len > 28 ? 28 : len' ternary in
    the tx-status info-line wrap (we're inside the else branch so the
    ternary always picks 28). Restate the tail clamp as a single
    conditional that cppcheck can prove safe.
2026-06-04 Fix code-level security audit findings (F-04, F-06..F-15, F-18, F-19)
    - F-04: copy card PIN into the sign request at the last moment and scrub
    it with CW_Utils::secure_wipe right after wallet.sign()
    - F-06: block on a first SNTP sync before any HTTPS request so TLS
    validity-period checks run against real time
    - F-07: parse_address now requires exactly 40 hex chars, rejects non-hex
    input and returns an error instead of decoding garbage
    - F-08: bound calldata_len against the RLP scratch buffer up front
    - F-09: do_post requires HTTP 200; JSON-RPC responses parsed with cJSON;
    nonce bounded to 2^32-1 and strtoull validated
    - F-10: ecrecover parity failures are explicit (mismatch vs RPC er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
    [config.template.h, main.cpp]
2026-06-04 Replace vendored TFT_eSPI/XPT2046 with pinned git submodules (F-20)
    The in-tree copies were verified file-by-file against upstream: exact
    snapshots of Bodmer/TFT_eSPI@cbf06d7a and
    PaulStoffregen/XPT2046_Touchscreen@f956c5d8 with no local source patches
    (only the ESP-IDF CMakeLists glue, now in wrapper components).
    - components/<name>/ keeps the IDF glue (CMakeLists, Kconfig rsource)
    - components/<name>/<name>/ is the pristine upstream submodule
    - provenance, layout and update procedure documented in
    components/VENDORED.md
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2026-06-04 eth_rpc: include CW_Utils.h before lwip-including IDF headers
    CW_Utils.h pulls in Arduino.h (via platform_compat.h), whose IPAddress.h
    declares 'extern const IPAddress INADDR_NONE'. lwip's inet.h defines
    INADDR_NONE as a macro, so the declaration fails to parse if any
    lwip-including header (esp_http_client.h, ...) comes first. Move the
    include above the IDF network headers and document the constraint.
2026-06-04 Switch cryptnox-sdk-esp32 submodule to main (08ff49a)
    feature/esp32-cyd was fully merged into the SDK's main (PR #20), which
    has since gained Doxygen docs, SPDX headers, safe_memcpy hardening in
    examples, PN532 SPI init fixes, the -Wmissing-field-initializers fixes
    and dropped the unused EPD driver. Nothing CYD-specific remains on the
    branch that this project needs — its display/touch/demo code already
    lives here. Track main from now on.
2026-06-04 sdkconfig.defaults: document the two expected TFT_eSPI build warnings
    'Invalid Reset pin' (TFT_RST=-1: panel reset shares the board EN line,
    driver falls back to SWRESET) and 'TOUCH_CS pin not defined' (XPT2046
    sits on its own SPI bus, owned by the XPT2046_Touchscreen component).
    Both are hardware-accurate; kept visible on purpose rather than
    silenced via CONFIG_DISABLE_WARNINGS.
2026-06-04 Restore PN532 init visibility, mute I2C busy-poll noise, log tx hash
    - pn532 tag back to INFO: the SDK's per-APDU log flood was trimmed
    upstream, INFO now only emits the init lines (wake-up, firmware
    frame, 'PN532 initialized') worth keeping
    - i2c.master tag muted: the PN532 NACKs its own address while busy
    (normal protocol), IDF's driver logged a 4-line error burst per poll;
    real failures still propagate through SDK return codes
    - eth_rpc: log the tx hash returned by eth_sendRawTransaction (public
    on-chain data, handy for Etherscan lookup)
    [main.cpp]
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2026-06-05 ui: rebuild the touchscreen UI on LVGL 8.x (dark-fintech theme)
    Replace the immediate-mode TFT_eSPI screens with an LVGL widget UI.
    TFT_eSPI is now only the low-level panel driver (LVGL flush callback);
    XPT2046 feeds the LVGL pointer input. anti-aliased Montserrat fonts, a
    single mint accent on a slate background, flat rounded buttons.
    - main/idf_component.yml: add lvgl/lvgl ^8 (public)
    - main/CMakeLists.txt: require lvgl
    - sdkconfig.defaults: LVGL config (16bpp, 48KB mem, Montserrat 14/20/28/48)
    - main/ui.cpp: LVGL plumbing (partial draw buf, flush via TFT_eSPI, touch
    read, esp_timer tick) + splash/amount/confirm/tx-status screens. Public
    ui_*/event API unchanged, so main.cpp is untouc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
2026-06-05 settings: persist backlight in NVS; fix divider/burger overlap
    - New settings module (main/settings.{h,cpp}): NVS namespace 'settings'
    with brightness + Wi-Fi credential getters/setters and safe defaults.
    - ui: restore saved brightness at boot; persist on slider release / modal
    close (not per-tick — spares the flash). Move the section divider down
    to y=42 so it clears the burger button, and nudge the amount values
    down to clear the divider.
    - main: run nvs_flash_init() before ui_init() so the UI task reads saved
    settings without racing the flash init.
    [main.cpp]
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2026-06-05 ui+main: enter the card PIN on a keypad instead of hard-coding it
    Replaces the config.h CARD_PIN with a runtime PIN entry screen.
    - New PIN screen (UI_SCREEN_PIN): masked password textarea + numeric
    lv_btnmatrix keypad (digits, backspace, OK) and a back/cancel button.
    Confirm 'Send' now opens this screen instead of signing directly.
    - On OK the PIN is staged and UI_EVENT_PIN_ENTERED is emitted; main
    fetches it via ui_take_pin() (which secure-wipes the UI's copy),
    passes it to sign_and_broadcast(), then wipes its own copy (F-04).
    - sign_and_broadcast() takes the PIN as a parameter; CARD_PIN /
    CARD_PIN_LEN and the F-14 demo-PIN build guard are gone.
    Closes the hard-coded-PIN weakne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
    [main.cpp]
2026-06-05 eth_rpc: harden SNTP time sync (multiple servers + retries)
    pool.ntp.org alone timed out on a phone-hotspot uplink. Use three
    servers (time.google.com, pool.ntp.org, time.cloudflare.com) via
    ESP_NETIF_SNTP_DEFAULT_CONFIG_MULTIPLE and poll across the timeout
    budget; main retries the whole sync up to 3 rounds before failing the
    boot, instead of dead-ending on the first miss.
    [main.cpp]
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2026-06-05 ui: Wi-Fi provisioning UI + tabbed settings (Screen/Wi-Fi/Tx/About)
    C2 of the provisioning work — network picker reachable from the burger:
    - Settings modal rebuilt as an lv_tabview:
    * Screen - brightness slider + auto (light-sensor) checkbox
    * Wi-Fi - 'Scan networks' button
    * Tx - read-only USDC contract + destination address (from main
    via ui_set_addresses)
    * About - product line, cryptnox-sdk-esp32 1.0.0, (c) Cryptnox 2026,
    educational-use note
    - Wi-Fi flow: scan list (lv_list) -> password keyboard (lv_keyboard) ->
    connect. Scan/connect run in the main task (UI stays responsive);
    creds persisted to NVS, fall back to re-scan on failure.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
    [main.cpp]
2026-06-05 ui: portrait layout, amount keypad, factory reset, forced first-run Wi-Fi
    - Orientation: switch the panel + touch to portrait (240x320) — natural
    for a hand-held POS. All modals/buttons/keypads re-fitted to 240 wide
    and the keypads enlarged to use the extra height.
    - Amount screen: replace the +/- steppers with a numeric keypad (digits,
    '.', backspace); drop the title/divider for space; the action button is
    now 'Charge'. Amount parsed from the typed string, reset on each entry.
    - Factory reset: settings_factory_reset() erases the NVS namespace; a
    'Reset' button in the settings About tab opens a confirm popup
    (Cancel / Erase) that wipes settings + Wi-Fi and reboots.
    - C2d: ensur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
    [main.cpp]
2026-06-05 ui: fix inverted panel colours (invertDisplay) + flat button fill
    The CYD ILI9341 panel renders colours inverted (a red test button showed
    cyan), which made black buttons look white and the blue accent look off.
    Call tft.invertDisplay(true) at init so every colour renders correctly.
    Also force a flat button fill (LV_GRAD_DIR_NONE + opaque) so the theme's
    default gradient can't wash dark fills toward light. Charge/Send back to
    black bg + white text.
2026-06-05 ui: SumUp-style light theme + redesigned transaction flow
    - Light theme: white background, black ink, flat buttons, borderless icon
    burger; minimal cents keypad (00 key, no boxes, digits shift in).
    - Amount screen: large amount + USDC badge that tracks it; 'Charge'.
    - Send (was Confirm) screen: roomier, larger wrapped 'To:' address,
    USDC badge; Cancel / Confirm.
    - Transaction screen: card icon + 'Tap your card' + Total while waiting;
    animated spinner during 'Signing' / 'Authorizing'; big pop-in check
    (green) / cross (light red) with POS wording 'Approved' / 'Declined'
    and a full-width 'New sale'.
    - USDC + card images generated from assets/ via tools/gen_*; silence the
    unavoidable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
2026-06-05 main: give 60 s to present the card (time-based connect loop)
    Replace the attempt-count card-connect loop with an esp_timer-based 60 s
    window so the operator has a full minute to tap the card; Cancel still
    aborts immediately.
    [main.cpp]
2026-06-05 ui: About logo/version, USDC badge alignment, Reset + Wi-Fi tab polish
    - About tab: dedicated 40px logo (logo_small) above the name, 'v1.0' version line, page made vertically scrollable so the text fits
    - USDC badge vertically centred beside the amount on every screen (amount entry, Send/confirm, transaction Total + Done amount)
    - Reset confirm popup: stacked full-width Erase/Cancel buttons in a taller card (the side-by-side pair overlapped under the card padding)
    - Wi-Fi tab: show the currently configured SSID before 'Scan networks'
    - settings: align the first-tab section headings to a common top offset
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2026-06-06 Editable gas fees in settings + instant card-tap feedback (Processing)
    Gas fees (Tx tab):
    - max fee / priority fee (Gwei) now editable with +/- steppers in the
    settings Tx tab, persisted to NVS on Close; first-boot defaults come
    from config.h (MAX_FEE / MAX_PRIORITY_FEE), factory reset restores them
    - main.cpp builds the tx from the stored values (Gwei -> wei) and clamps
    the tip to the cap; GAS_LIMIT_ERC20 stays compile-time
    - config.template.h: realistic defaults (80/20 Gwei), gas limit aligned
    to the tested 100k, comment the runtime-editable behaviour
    Card flow:
    - new UI_TX_STATE_PROCESSING: spinner + 'Processing' as soon as the tap
    is detected, back to 'Tap your card' if the ca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
    [config.template.h, main.cpp]
2026-06-06 Wait for the mined receipt before showing Approved
    A broadcast acceptance only means the tx entered the mempool — the
    terminal claimed Approved without any network confirmation. Now:
    - eth_rpc: new eth_rpc_get_tx_receipt() polling
    eth_getTransactionReceipt (dedicated 4 KB heap buffer: logsBloom +
    the Transfer log overflow the standard 1 KB response buffer)
    - new UI_TX_STATE_CONFIRMING spinner state ('Confirming') between
    broadcast and the verdict
    - main: poll the receipt every 4 s for up to 120 s; Approved only on
    status 0x1, 'Payment reverted' on status 0x0, 'Confirmation timeout -
    check explorer' otherwise; transient RPC errors keep polling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
    [main.cpp]
2026-06-06 ui: Ledger-style Send review + header/Wi-Fi tab polish
    - Send screen redesigned as a Ledger-style transaction review: left-
    aligned caption/value rows showing the amount, the full beneficiary
    address AND the full USDC contract address (what you see is what you
    sign)
    - drop the trailing ':' from caption labels app-wide for consistency
    (Tx tab, fees, Total, Signal)
    - Wi-Fi tab: Signal as a caption/value pair under the SSID, Scan
    networks full-width, ACT_BTN_H tall, placed right below the info block
    - header titles in montserrat_20, optically centred above the divider
    - burger menu only on the amount screen: settings can no longer be
    opened mid-transaction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
2026-06-08 Add optional flash-encryption + encrypted-NVS secure build
    Closes audit findings F-16 (NVS stored in plaintext) and the at-rest
    half of F-01/F-02 (a flash dump no longer yields the Wi-Fi password or
    any NVS secret). Opt-in, layered on top of the normal build so the dev
    kit stays unencrypted by default.
    - sdkconfig.defaults.flash_encryption: overlay enabling Flash Encryption
    (Development mode), CONFIG_NVS_ENCRYPTION, and PARTITION_TABLE_OFFSET
    bumped to 0xC000 (the FE bootloader grows past the 0x8000 default)
    - partitions.csv: add the flash-encrypted nvs_keys partition; blank
    offsets so partitions auto-place after the moved table
    - tools/secure_flash.py: pre-encrypt the images with the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
    [partitions.csv]
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2026-06-08 test: add libFuzzer harnesses + runner for the eth parsers
    Three coverage-guided + ASan harnesses, each #including the production .cpp
    directly (no copies -> they can never drift from the firmware):
    - fuzz_eth_rlp -> eth_rlp_encode_unsigned/_signed
    - fuzz_parse_address -> eth_addr_parse
    - fuzz_eth_rpc_json -> eth_json_result_string + eth_json_receipt_status
    Plus CMakeLists.txt (clang/libFuzzer), run_fuzz.ps1 (Windows build+run helper:
    enters the VS dev env for MSVC/SDK headers, wires the ASan runtime DLL,
    resolves corpus/cJSON/SDK paths), a README, curated seed corpora and a
    .gitignore for build outputs and libFuzzer-generated units.
    Run locally: ~14.5M executions across the thr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
    [fuzz_eth_rlp.cpp]
2026-06-08 harden: route eth_rlp copies through safe_memcpy, scrub crypto scratch
    CODING_RULES 1.4: replace the documented raw-memcpy exception in eth_rlp.cpp
    with CW_Utils::safe_memcpy, threading the destination capacity through the RLP
    helpers and propagating a 0 (failure) return. The post-guard return-value
    checks in the public encoders are tautological after the up-front
    'total > out_max' check but kept as defence in depth.
    sign_and_broadcast now scrubs the message hash, signature and encoded
    transactions on every exit path via a small RAII WipeGuard (the SDK examples
    wipe testHash + signResult.signature; this matches that rigour without a
    secure_wipe before each of the ~10 returns). PIN scrub (F-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
    [fuzz_eth_rlp.cpp, main.cpp]
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2026-06-09 docs: group cryptnox-pos sources into Doxygen modules (SDK parity)
    Mirror the SDK's Doxygen organisation (CW_Defs.h-style @defgroup taxonomy):
    add main/groups.dox defining app / eth / device / ui, and tag every source
    file with @ingroup so the generated docs are organised by subsystem instead of
    a flat file list. Add the missing @file blocks to eth_addr.cpp / eth_json.cpp.
    Fix the doc gaps the local doxygen 1.15.0 run surfaced: document
    sign_and_broadcast's pin / pin_chars params, drop an unresolvable @ref to the
    anonymous-namespace WipeGuard, and set MARKDOWN_ID_STYLE=GITHUB so the README's
    GitHub-style anchor links resolve (README untouched). Exclude the generated
    LVGL image blobs from th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
    [main.cpp]
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2026-07-21 feat(hardening): add EIP-55 checksum, dual-stored amount/recipient, bool32 verdict gate, and fail-closed anomaly logging to the payment path (HARDENING.md §7)
    [main.cpp]
2026-07-25 fix(hardening): address review — mandate EIP-55 for ADDR_TO/USDC with an all-lowercase boot warning, store the amount echo as a bitwise complement, and force the decision-gate witnesses to RAM via vo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
    [config.template.h, main.cpp]
2026-07-28 fix(hardening): address PR #1 review — move host tests to tests/units, single-exit decision gate, doxygen and ETH_ADDR_LEN/calldata defines, and distinguish NVS read errors
    [main.cpp]
2026-07-28 fix(startup): report bring-up faults on their own screen, keep the splash up
    A wiring problem used to render as "Transaction / Declined / Wallet init failed"
    and then return from app_main, leaving the terminal stuck on what reads as a
    refused sale until a power cycle.
    - new UI_SCREEN_BOOT_ERROR names the cause and the fix; the transaction screen
    is no longer reused for hardware faults
    - probe the PN532 with GetFirmwareVersion. pn532_init() returns ESP_OK with no
    reader attached - its internal probe results are documented as intentionally
    ignored - so an absent reader was reported as a wallet fault
    - retry the saved Wi-Fi credentials instead of ejecting to the picker after a
    single f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
    [main.cpp]
2026-07-28 fix(startup): address review — persist Wi-Fi only once the clock syncs, measure the picker note band, and guard the boot-error detail from overprinting
    [main.cpp]
2026-07-29 fix(startup): prove the uplink before saving Wi-Fi from settings
    The settings Wi-Fi change persisted credentials as soon as the association
    succeeded, so a captive portal or an offline AP was written to NVS and then
    reached for on every later boot — the same defect the boot path already
    fixed. It now requires a clock sync over the new network, and reopens the
    picker with the reason when that fails.
    net_time_sync() had to become re-entrant for that: the wrapper refuses to
    re-init while still subscribed, so any second call failed outright. It now
    drops and re-arms per call, which also makes each call wait for a genuinely
    fresh packet instead of trusting the previous network's sync, and it s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
    [main.cpp]
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2026-07-29 feat(ui): lock the settings menu behind an admin code, greet on first run
    Anyone alone with the terminal for ten seconds could open the burger menu and
    factory-reset it, or point it at a network of their choosing. Funds were never
    at risk — TLS pinning and the card PIN hold — but availability was, and the
    reset is one confirmation away.
    One lock covers the whole menu rather than the individual entries: Wi-Fi, fee
    caps and the reset are all merchant operations, so gating the entry point is
    both simpler to audit and harder to get wrong. request_screen(UI_SCREEN_SETTINGS)
    now appears exactly once in the file, on the branch that follows a correct code.
    The code is created on first run, bef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
    [main.cpp]
2026-07-30 fix(tls): enforce certificate dates and constrain the clock they're checked against
    [main.cpp]
2026-07-30 fix(startup): restore the saved Wi-Fi when a settings change fails the clock check
    [main.cpp]
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2026-08-13 Refuse a Tron raw_data whose expected byte run only appears out of byte alignment, show the recipient that will actually be paid, and make the update endpoint impose the panel's wrong-code wait
    [config.template.h, main.cpp, provision.cpp]
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2026-08-26 Put the asset selector back above the amount with the ticker beside the figure, show the real card front on the config page as Cryptnox POS, and keep the AP passphrase until a factory reset
    [provision.cpp]
2026-08-27 Stop the config page's deadline withdrawing firmware that is waiting on the panel, say when an update rolled back, and swap the dead online update check for a Browse picker
    [main.cpp, provision.cpp]
2026-08-31 Charge in ETH, POL, USDT and USDC across Ethereum Sepolia, Polygon Amoy and Tron Nile, and say why a node refused a sale instead of only that the broadcast failed
    [config.template.h]
2026-09-03 Follow the asset picker with the Tx tab's addresses, verify the PIN before signing, say why a card read failed, clear the settings after a confirmed firmware update, and add a CodeQL scan
    [main.cpp]
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2026-09-24 Move the setup and admin code screens into the card, show Wi-Fi errors on the panel, shrink the tap mark, and fix text crowding buttons.
    [main.cpp, provision.cpp]
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2026-09-29 Fix the CodeQL cJSON include and the cppcheck findings in main.cpp and ui.cpp.
    [main.cpp]
2026-09-29 Keep the terminal running unattended: re-join Wi-Fi in the background, restart on boot faults, persist the in-flight sale, reset on a hung loop, confirm updates once the hardware is up, harden TLS, a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
    [main.cpp]
2026-09-30 Run the host tests, fuzzers and firmware build in CI, add known-answer tests for the money and settings code by moving it into money.h and settings_rules.h, replay the enlarged fuzz corpora without c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
    [main.cpp, provision.cpp]
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2026-10-01 Resolve the PR #12 security review: hide the customer PIN, keep the boot network until restart, wipe secret fields, gate Wi-Fi-only setup and fees, and fix the swipe filter and portal layout.
    [main.cpp, provision.cpp]
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

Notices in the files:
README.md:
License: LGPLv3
